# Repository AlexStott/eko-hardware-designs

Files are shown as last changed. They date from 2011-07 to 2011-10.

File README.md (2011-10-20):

Energy Kiosk Observer Hardware Schematics
=========================================

This project includes hardware schematics for the Energy Kiosk Observer datalogging system for e.quinox (www.e.quinox.org).

Cadsoft EAGLE is the tool of choice when designing PCBs, although some designs are being moved to RS DesignSpark.

Contents
--------

The following designs are included in this repository

* [AC Sensors](http://e.quinox.org/wiki/Datalogger:AC_Sensors): Isolated Power Sensing for 230VAC lines rated at 15A~.
* [Atmospheric](http://e.quinox.org/wiki/Datalogger:Atmospheric_Sensors): Light, Temperature and Humidity Sensing Package.
* [DC Sensor Solar](http://e.quinox.org/wiki/Datalogger:DC_Sensors): A 3x current, 1x voltage sensor package for power measurements on parallel connected solar panels.
* [DC Sensor](http://e.quinox.org/wiki/Datalogger:DC_Sensors): A 1x current, 1x voltage DC power sensor prototype rated at 30A~.
* [EKO Base](http://e.quinox.org/wiki/Datalogger:Mainboard): The Datalogger Mainboard with Network connectors and GPRS/3G modem.
* [Panelised]: Panelised designs for distribution to fabricator.
* [RS232_Barcode_Interface](http://e.quinox.org/wiki/Datalogger:Barcode_Scanner): An interface to a RS232 barcode scanner. Built for use with the SureElectronics PIC24F starter kit.
* [StorageBat_PSU](http://e.quinox.org/wiki/Datalogger:Battery_Sensors): A 1x voltage sensor for measurement of battery voltages.
* [Test_RS485](http://e.quinox.org/wiki/Datalogger:Test_Tools): A FTDI UM232 to RS485 adaptor utilising a SP483E line driver.
* [ekobbr2](http://e.quinox.org/wiki/Datalogger:Baseboard): PIC24F based sensor baseboard design.

Notes
-----

Currently the BoMs for these designs are not included in the repository. Order summaries are available on docs.ekohub.org or through the technical team wiki.

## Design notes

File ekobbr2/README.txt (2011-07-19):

Energy Kiosk Observer - Revision 1 AC sensor board 230V/5A
==========================================================

Design: Charith Amarasinghe

Designs
-------
Baseboard.brd/baseboard.sch - Revision 3 of the generic EKO sensor board

Features
********
PIC24F16KA102 in SOIC packaging
Integrated 32.768kHz crystal oscillator
3x Diagnostic LEDs (Power,TX,RX)
RX/TX can be disconnected from SP483E driver
Transient Voltage Suppressors on All Bus Lines
Interrupt Line

Changes from R2
***************
Included chip 7407D, 6x buffer instead of single buffer
Included Interrupt line connected to Pic AN2
Removed 2x debug LEDs
Removed end of sensor cable jumpers + resistors

Changes from R1
***************
All SMT components
PCB Stacking vs. Wire Connectors

Libraries
---------

eko-parts.lbr   - main eko-parts eagle library

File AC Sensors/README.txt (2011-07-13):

Energy Kiosk Observer - Revision 1 AC sensor board 230V/5A
==========================================================

Design: Azrul Mohamad

Designs
--------

ACBoard1.brd/ACBoard1.sch - Initial design, obsolete
ACBoard2.brd/ACBoard2.sch - Current, docks with Revision 2 SBB

Libraries
---------

Pauls_parts.lbr - Symbol for ACS712, Myrra Xfmr. Rename.
eko-parts.lbr   - Older version of main eko-parts eagle library (Consolidate)
Sensor.lbr	- Obsolete

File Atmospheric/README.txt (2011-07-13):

Energy Kiosk Observer - Revision 1 Atmospheric Sensor Humidity/Light/Temperature
=================================================================================

Design: Azrul Mohamad
Layout: Charith Amarasinghe

Boards
------

Atmospheric.brd/Atmospheric.sch - Atmospheric sensor for Revision 2 SBB
Supports accurate temperature measurement with a MCP9800
Light measured to human-eye response (Lux) by TAOS TSL2561
Relative Humidity measurement with Honeywell humidity sensor (capacitive, use PIC CTMU to measure)

Changes
------

07/06/2011	 Initial revision sent for manufacture
13/06/2011	 Increased mounting hole size to M3
		 
Libraries
--------

Atmospheric.lbr - TSL2561, MCP9800 and Generic Cap

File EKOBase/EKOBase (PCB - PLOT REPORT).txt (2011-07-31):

PLOT REPORT
-----------

Report File    : C:\Users\ca508\Dropbox\eagle\eko-hardware-designs\EKOBase\EKOBase (PCB - PLOT REPORT).txt
Report Written : Monday, August 01, 2011
Project Path   : C:\Users\ca508\Dropbox\eagle\eko-hardware-designs\EKOBase\EKOBase.prj
Design Path    : C:\Users\ca508\Dropbox\eagle\eko-hardware-designs\EKOBase\EKOBase.pcb
Design Title   : 
Created        : 28/05/2011 14:42:59
Last Saved     : 31/07/2011 23:47:38
Editing Time   : 3080 min
Units          : mm (precision 4)

DEVICE SETTINGS
---------------

---------------
Gerber Settings
---------------

    Leading zero suppression.
    G01 assumed throughout.
    Line termination <*> <CR> <LF>.
    2.3 format absolute inches.

    Format commands defined in Gerber file.
    Aperture table defined in Gerber file.
    Hardware arcs allowed.

--------------
Drill Settings
--------------

    Excellon Format 1
    Format 2.3 absolute in mm.
    No zero suppression.

PLOTS OUTPUT
------------
    Plot Job: "C:\Users\ca508\Dropbox\eagle\eko-hardware-designs\EKOBase\EKOBase.mop"

Gerber Output
-------------

    "C:\Users\ca508\Dropbox\eagle\eko-hardware-designs\EKOBase\Gerber\EKOBase - Top Silkscreen.gbr"

    Layers:
    -------
    Top Silkscreen

    D-Code    Shape  (thou)
    -----------------------
    D22       Round 1
    D96       Round 10
    D97       Round 16
    D98       Round 8
    D111       Round 6
    D113       Round 4
    D115       Round 5
    D124       Round 3
    D146       Round 16
    D147       Round 12
    D148       Round 8
    D149       Round 3
    D150       Round 4
    D151       Round 20
    D152       Round 12
    D153       Round 3
    D154       Round 0

Gerber Output
-------------

    "C:\Users\ca508\Dropbox\eagle\eko-hardware-designs\EKOBase\Gerber\EKOBase - Top Copper.gbr"

    Layers:
    -------
    Top Copper

    D-Code    Shape  (thou)
    -----------------------
    D22       Round 1
    D95       Round 32
    D96       Round 10
    D99       Round 55
    D102       Square 60
    D103       Octagon 60
    D104       Square 70
    D105       Octagon 70
    D148       Round 8
    D150       Round 0
    D151       Square 236
    D152       Round 60
    D153       Rectangle 22 X 78 Rotation 90
    D154       Rectangle 16 X 36
    D155       Rectangle 39 X 43
    D156       Rectangle 27 X 39 Rotation 90
    D157       Rectangle 161 X 163 Rotation 90
    D158       Rectangle 51 X 60
    D159       Rectangle 39 X 43 Rotation 90
    D160       Rectangle 51 X 60 Rotation 90
    D161       Oval 60 X 110 Rotation 90
    D162       Rectangle 24 X 87
    D163       Oval 60 X 110
    D164       Rectangle 63 X 71 Rotation 90
    D165       Rectangle 63 X 71
    D166       Rectangle 70 X 93
    D167       Round 160
    D168       Rectangle 161 X 163
    D169       Rectangle 43 X 82 Rotation 90
    D170       Rectangle 105 X 132
    D171       Rectangle 80 X 95
    D172       Square 95
    D173       Rectangle 24 X 60
    D174       Round 86
    D175       Rectangle 18 X 39 Rotation 90
    D176       Rectangle 80 X 95 Rotation 90
    D177       Round 60
    D178       Rectangle 17 X 69 Rotation 90
    D179       Rectangle 47 X 169 Rotation 90
    D180       Rectangle 47 X 79 Rotation 90
    D181       Rectangle 83 X 94 Rotation 90
    D182       Rectangle 102 X 114 Rotation 90
    D183       Rectangle 51 X 75 Rotation 90
    D184       Rectangle 55 X 77 Rotation 90
    D185       Rectangle 83 X 87 Rotation 90
    D186       Round 70
    D187       Round 60
    D188       Round 56
    D189       Round 48
    D190       Round 30
    D191       Round 24
    D192       Round 15
    D193       Round 50

Gerber Output
-------------

    "C:\Users\ca508\Dropbox\eagle\eko-hardware-designs\EKOBase\Gerber\EKOBase - Top Copper (Paste).gbr"

    Layers:
    -------
    Top Copper

    D-Code    Shape  (thou)
    -----------------------
    D10       Rectangle 18 X 74 Rotation 90
    D11       Rectangle 12 X 32
    D12       Rectangle 35 X 39
    D13       Rectangle 23 X 35 Rotation 90
    D14       Rectangle 157 X 159 Rotation 90
    D15       Rectangle 47 X 56
    D16       Rectangle 35 X 39 Rotation 90
    D17       Rectangle 47 X 56 Rotation 90
    D18       Rectangle 20 X 83
    D19       Rectangle 59 X 67 Rotation 90
    D70       Rectangle 59 X 67
    D71       Rectangle 66 X 89
    D20       Rectangle 157 X 159
    D21       Rectangle 39 X 78 Rotation 90
    D22       Rectangle 101 X 128
    D23       Rectangle 76 X 91
    D24       Square 91
    D25       Rectangle 20 X 56
    D26       Rectangle 14 X 35 Rotation 90
    D27       Rectangle 76 X 91 Rotation 90
    D28       Rectangle 13 X 65 Rotation 90
    D29       Rectangle 43 X 165 Rotation 90
    D72       Rectangle 43 X 75 Rotation 90
    D73       Rectangle 79 X 90 Rotation 90
    D74       Rectangle 98 X 110 Rotation 90
    D75       Rectangle 47 X 71 Rotation 90
    D76       Rectangle 51 X 73 Rotation 90
    D77       Rectangle 79 X 83 Rotation 90

Gerber Output
-------------

    "C:\Users\ca508\Dropbox\eagle\eko-hardware-designs\EKOBase\Gerber\EKOBase - Top Solder Mask.gbr"

    Layers:
    -------
    Top Solder Mask

    D-Code    Shape  (thou)
    -----------------------
    D78       Square 242
    D79       Round 8
    D80       Round 66
    D81       Square 76
    D82       Octagon 70
    D83       Square 66
    D84       Octagon 60
    D85       Rectangle 28 X 84 Rotation 90
    D86       Rectangle 22 X 42
    D87       Rectangle 45 X 49
    D88       Rectangle 33 X 45 Rotation 90
    D89       Rectangle 167 X 169 Rotation 90
    D90       Rectangle 57 X 66
    D91       Rectangle 45 X 49 Rotation 90
    D92       Rectangle 57 X 66 Rotation 90
    D93       Oval 66 X 116 Rotation 90
    D94       Rectangle 30 X 93
    D95       Oval 66 X 116
    D96       Rectangle 69 X 77 Rotation 90
    D97       Rectangle 69 X 77
    D98       Rectangle 76 X 99
    D99       Round 61
    D100       Round 166
    D101       Rectangle 167 X 169
    D102       Rectangle 49 X 88 Rotation 90
    D103       Rectangle 111 X 138
    D104       Rectangle 86 X 101
    D105       Square 101
    D106       Rectangle 30 X 66
    D107       Round 92
    D108       Rectangle 24 X 45 Rotation 90
    D109       Rectangle 86 X 101 Rotation 90
    D110       Round 66
    D111       Rectangle 23 X 75 Rotation 90
    D112       Rectangle 53 X 175 Rotation 90
    D113       Rectangle 53 X 85 Rotation 90
    D114       Rectangle 89 X 100 Rotation 90
    D115       Rectangle 108 X 120 Rotation 90
    D116       Rectangle 57 X 81 Rotation 90
    D117       Rectangle 61 X 83 Rotation 90
    D118       Rectangle 89 X 93 Rotation 90
    D119       Round 76
    D120       Round 1
    D121       Round 66
    D122       Round 62
    D123       Round 54
    D124       Round 38

Gerber Output
-------------

    "C:\Users\ca508\Dropbox\eagle\eko-hardware-designs\EKOBase\Gerber\EKOBase - Bottom Copper.gbr"

    Layers:
    -------
    Bottom Copper

    D-Code    Shape  (thou)
    -----------------------
    D79       Round 8
    D106       Round 10
    D107       Square 70
    D108       Octagon 70
    D109       Square 60
    D110       Octagon 60
    D111       Rectangle 70 X 93 Rotation 90
    D112       Round 55
    D113       Round 32
    D114       Round 20
    D150       Round 0
    D151       Square 236
    D152       Round 60
    D155       Rectangle 39 X 43
    D158       Rectangle 51 X 60
    D159       Rectangle 39 X 43 Rotation 90
    D160       Rectangle 51 X 60 Rotation 90
    D161       Oval 60 X 110 Rotation 90
    D163       Oval 60 X 110
    D165       Rectangle 63 X 71
    D167       Round 160
    D174       Round 86
    D177       Round 60
    D186       Round 70
    D187       Round 60
    D188       Round 56
    D189       Round 48
    D190       Round 30
    D191       Round 24
    D192       Round 15
    D193       Round 50

Gerber Output
-------------

    "C:\Users\ca508\Dropbox\eagle\eko-hardware-designs\EKOBase\Gerber\EKOBase - Bottom Copper (Paste).gbr"

    Layers:
    -------
    Bottom Copper

    D-Code    Shape  (thou)
    -----------------------
    D10       Rectangle 66 X 89 Rotation 90
    D11       Rectangle 59 X 67
    D12       Rectangle 47 X 56
    D13       Rectangle 47 X 56 Rotation 90
    D14       Rectangle 35 X 39
    D15       Rectangle 35 X 39 Rotation 90

Gerber Output
-------------

    "C:\Users\ca508\Dropbox\eagle\eko-hardware-designs\EKOBase\Gerber\EKOBase - Bottom Silkscreen.gbr"

    Layers:
    -------
    Bottom Silkscreen

    D-Code    Shape  (thou)
    -----------------------
    D16       Round 25
    D17       Round 8
    D18       Round 5
    D19       Round 8

Gerber Output
-------------

    "C:\Users\ca508\Dropbox\eagle\eko-hardware-designs\EKOBase\Gerber\EKOBase - Bottom Solder Mask.gbr"

    Layers:
    -------
    Bottom Solder Mask

    D-Code    Shape  (thou)
    -----------------------
    D17       Round 8
    D70       Square 242
    D71       Round 66
    D20       Square 76
    D21       Octagon 70
    D22       Square 66
    D23       Octagon 60
    D24       Rectangle 76 X 99 Rotation 90
    D25       Oval 66 X 116 Rotation 90
    D26       Oval 66 X 116
    D27       Round 61
    D28       Round 166
    D29       Round 92
    D72       Rectangle 69 X 77
    D73       Round 66
    D74       Round 76
    D75       Rectangle 57 X 66
    D76       Rectangle 57 X 66 Rotation 90
    D77       Round 66
    D78       Rectangle 45 X 49
    D79       Rectangle 45 X 49 Rotation 90
    D80       Round 62
    D81       Round 54
    D82       Round 38

NC Drill Output
---------------

    Output:
    -------
    Plated Round Drill Holes
    Plated Slots
    Plated Board Outlines

    "C:\Users\ca508\Dropbox\eagle\eko-hardware-designs\EKOBase\Gerber\EKOBase - Drill Data - Through Hole.drl"

    Tool             Size        Count  ID
    --------------------------------------
    T001        00.016 in           49   L
    T002        00.024 in           15   B
    T003        00.030 in           28   C
    T004        00.032 in           94   E
    T005        00.035 in            2   K
    T006        00.035 in           24   F
    T007        00.040 in           10   D
    T008        00.055 in            2   J
    T009        00.062 in            4   H
    T010        00.128 in            6   G
    T011        00.154 in            8   A
    --------------------------------------
    All                            242
    --------------------------------------

NC Drill Output
---------------

    Output:
    -------
    Unplated Round Drill Holes
    Unplated Slots
    Unplated Board Outlines

    "C:\Users\ca508\Dropbox\eagle\eko-hardware-designs\EKOBase\Gerber\EKOBase - Drill Data - Through Hole (Unplated).drl"

    Tool             Size        Count  ID
    --------------------------------------
    T001        00.025 in            1   
    --------------------------------------
    All                              1
    --------------------------------------

Gerber Output
-------------

    "C:\Users\ca508\Dropbox\eagle\eko-hardware-designs\EKOBase\Gerber\EKOBase - Drill Ident Drawing - Through Hole.gbr"

    Layers:
    -------

    Drill Ident Drawing
    -------------------

    Drill     Plated    Size      Shape     ID        
    --------------------------------------------------
    154       Y         100       Round     A         
    24        Y         100       Round     B         
    30        Y         100       Round     C         
    40        Y         100       Round     D         
    32        Y         100       Round     E         
    35        Y         100       Round     F         
    128       Y         100       Round     G         
    62        Y         100       Round     H         
    55        Y         100       Round     J         
    35        Y         100       Round     K         
    16        Y         100       Round     L         
    --------------------------------------------------

    D-Code    Shape  (thou)
    -----------------------
    D18       Round 5
    D83       Round 100

Gerber Output
-------------

    "C:\Users\ca508\Dropbox\eagle\eko-hardware-designs\EKOBase\Gerber\EKOBase - Board Outline.gbr"

    Layers:
    -------
    Board Outlines

    D-Code    Shape  (thou)
    -----------------------
    D18       Round 5

End Of Report.

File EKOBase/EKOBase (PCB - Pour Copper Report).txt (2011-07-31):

Pour Copper Report
------------------

Report File    : C:\Users\ca508\Dropbox\eagle\eko-hardware-designs\EKOBase\EKOBase (PCB - Pour Copper Report).txt
Report Written : Monday, August 01, 2011
Project Path   : C:\Users\ca508\Dropbox\eagle\eko-hardware-designs\EKOBase\EKOBase.prj
Design Path    : C:\Users\ca508\Dropbox\eagle\eko-hardware-designs\EKOBase\EKOBase.pcb
Design Title   : 
Created        : 28/05/2011 14:42:59
Last Saved     : 31/07/2011 23:43:01
Editing Time   : 3076 min
Units          : mm (precision 4)

End Of Report.

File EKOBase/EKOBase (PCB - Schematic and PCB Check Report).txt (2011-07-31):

Schematic and PCB Check Report
------------------------------

Report File    : C:\Users\ca508\Dropbox\eagle\eko-hardware-designs\EKOBase\EKOBase (PCB - Schematic and PCB Check Report).txt
Report Written : Monday, August 01, 2011
Project Path   : C:\Users\ca508\Dropbox\eagle\eko-hardware-designs\EKOBase\EKOBase.prj
Design Path    : C:\Users\ca508\Dropbox\eagle\eko-hardware-designs\EKOBase\EKOBase.pcb
Design Title   : 
Created        : 28/05/2011 14:42:59
Last Saved     : 31/07/2011 23:12:49
Editing Time   : 3044 min
Units          : mm (precision 4)

Checking integrity of Schematic "C:\Users\ca508\Dropbox\eagle\eko-hardware-designs\EKOBase\EKOBase.prj" with PCB "C:\Users\ca508\Dropbox\eagle\eko-hardware-designs\EKOBase\EKOBase.pcb".

End Of Report.

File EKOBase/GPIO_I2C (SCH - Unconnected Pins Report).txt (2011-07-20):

Unconnected Pins Report
-----------------------

Report File    : C:\Users\ca508\Dropbox\DesignSpark Projects\EKOBase\GPIO_I2C (SCH - Unconnected Pins Report).txt
Report Written : Saturday, May 28, 2011
Project Path   : C:\Users\ca508\Dropbox\DesignSpark Projects\EKOBase\EKOBase.prj
Design Path    : C:\Users\ca508\Dropbox\DesignSpark Projects\EKOBase\GPIO_I2C.sch
Design Title   : 
Created        : 
Last Saved     : 28/05/2011 00:56:19
Editing Time   : 801 min
Units          : thou (precision 2)

Component U1  Pin 6  A4
Component R4  Pin 3  
Component R4  Pin 4  
Component J1  Pin 1  
Component J1  Pin 25  
Component REF60  Pin 7  NC
Component REF60  Pin 8  INT
Component REF60  Pin 15  GP5
Component U6  Pin 1  NC
Component U6  Pin 4  NC
Component U7  Pin 1  NC
Component U7  Pin 4  NC
Component U9  Pin 1  NC
Component U9  Pin 4  NC
Component CONN1  Pin P$1  1
Component CONN1  Pin P$2  2
Component CONN1  Pin P$3  3
Component CONN1  Pin P$6  6
Component CONN2  Pin P$1  1
Component CONN2  Pin P$2  2
Component CONN2  Pin P$3  3
Component CONN2  Pin P$6  6
Component U11  Pin 1  NC
Component U11  Pin 4  NC
Component U12  Pin 1  NC
Component U12  Pin 4  NC

Unconnected pins found : 26

End Of Report.

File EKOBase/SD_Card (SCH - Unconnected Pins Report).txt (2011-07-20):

Unconnected Pins Report
-----------------------

Report File    : C:\Users\ca508\Dropbox\DesignSpark Projects\EKOBase\SD_Card (SCH - Unconnected Pins Report).txt
Report Written : Saturday, May 28, 2011
Project Path   : C:\Users\ca508\Dropbox\DesignSpark Projects\EKOBase\EKOBase.prj
Design Path    : C:\Users\ca508\Dropbox\DesignSpark Projects\EKOBase\SD_Card.sch
Design Title   : 
Created        : 
Last Saved     : 28/05/2011 03:20:28
Editing Time   : 1602 min
Units          : mil (precision 0)

Component U1  Pin 6  A4
Component J1  Pin 1  
Component J1  Pin 25  
Component REF60  Pin 7  NC
Component REF60  Pin 8  INT
Component REF60  Pin 15  GP5
Component U6  Pin 1  NC
Component U6  Pin 4  NC
Component U7  Pin 1  NC
Component U7  Pin 4  NC
Component U9  Pin 1  NC
Component U9  Pin 4  NC
Component CONN1  Pin P$1  1
Component CONN1  Pin P$2  2
Component CONN1  Pin P$3  3
Component CONN1  Pin P$6  6
Component CONN2  Pin P$1  1
Component CONN2  Pin P$2  2
Component CONN2  Pin P$3  3
Component CONN2  Pin P$6  6
Component U11  Pin 1  NC
Component U11  Pin 4  NC
Component U12  Pin 1  NC
Component U12  Pin 4  NC

Unconnected pins found : 24

End Of Report.

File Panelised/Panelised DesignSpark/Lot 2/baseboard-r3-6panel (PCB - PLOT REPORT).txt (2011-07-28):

PLOT REPORT
-----------

Report File    : C:\Users\ca508\Dropbox\eagle\eko-hardware-designs\Panelised\Panelised DesignSpark\Lot 2\baseboard-r3-6panel (PCB - PLOT REPORT).txt
Report Written : Thursday, July 28, 2011
Project Path   : C:\Users\ca508\Dropbox\eagle\eko-hardware-designs\Panelised\Panelised DesignSpark\Lot 2\Lot 2.prj
Design Path    : C:\Users\ca508\Dropbox\eagle\eko-hardware-designs\Panelised\Panelised DesignSpark\Lot 2\baseboard-r3-6panel.pcb
Design Title   : 
Created        : 27/07/2011 22:50:58
Last Saved     : 28/07/2011 00:26:40
Editing Time   : 105 min
Units          : thou (precision 0)

DEVICE SETTINGS
---------------

---------------
Gerber Settings
---------------

    Leading zero suppression.
    G01 assumed throughout.
    Line termination <*> <CR> <LF>.
    2.3 format absolute inches.

    Format commands defined in Gerber file.
    Aperture table defined in Gerber file.
    Hardware arcs allowed.

--------------
Drill Settings
--------------

    Excellon Format 1
    Format 2.3 absolute in mm.
    No zero suppression.

PLOTS OUTPUT
------------
    Plot Job: "C:\Users\ca508\Dropbox\eagle\eko-hardware-designs\Panelised\Panelised DesignSpark\Lot 2\baseboard-r3-6panel.mop"

Gerber Output
-------------

    "C:\Users\ca508\Dropbox\eagle\eko-hardware-designs\Panelised\Panelised DesignSpark\Lot 2\Gerber\baseboard-r3-6panel - Top Silk.gbr"

    Layers:
    -------
    Top Silk

    D-Code    Shape  (thou)
    -----------------------
    D22       Round 1
    D96       Round 10
    D97       Round 16
    D98       Round 8
    D109       Round 8
    D110       Round 5
    D111       Round 6
    D112       Round 4
    D113       Round 4
    D115       Round 5
    D116       Round 8
    D117       Round 17
    D118       Round 19
    D119       Round 9
    D120       Round 13
    D121       Round 11
    D122       Round 6
    D123       Round 2
    D124       Round 3
    D125       Round 7
    D126       Round 0
    D127       Round 7

Gerber Output
-------------

    "C:\Users\ca508\Dropbox\eagle\eko-hardware-designs\Panelised\Panelised DesignSpark\Lot 2\Gerber\baseboard-r3-6panel - Top.gbr"

    Layers:
    -------
    Top

    D-Code    Shape  (thou)
    -----------------------
    D95       Round 32
    D96       Round 10
    D97       Round 16
    D98       Round 8
    D99       Round 55
    D100       Round 136
    D102       Square 60
    D103       Octagon 60
    D104       Square 70
    D105       Octagon 70
    D106       Rectangle 51 X 59 Rotation 90
    D107       Octagon 40
    D108       Square 166
    D115       Round 5
    D128       Rectangle 43 X 39 Rotation 90
    D129       Rectangle 43 X 39
    D130       Rectangle 77 X 98
    D131       Rectangle 63 X 71 Rotation 90
    D132       Rectangle 100 X 98 Rotation 90
    D133       Rectangle 64 X 86 Rotation 90
    D134       Rectangle 24 X 87 Rotation 90
    D135       Rectangle 26 X 80 Rotation 90
    D136       Rectangle 24 X 59 Rotation 90
    D137       Rectangle 48 X 88 Rotation 90
    D138       Rectangle 142 X 87 Rotation 90
    D139       Square 157
    D140       Rectangle 46 X 63
    D141       Round 51
    D142       Round 59
    D143       Rectangle 24 X 43 Rotation 90
    D144       Rectangle 26 X 67

Gerber Output
-------------

    "C:\Users\ca508\Dropbox\eagle\eko-hardware-designs\Panelised\Panelised DesignSpark\Lot 2\Gerber\baseboard-r3-6panel - Top Mask.gbr"

    Layers:
    -------
    Top Mask

    D-Code    Shape  (thou)
    -----------------------
    D10       Rectangle 49 X 45 Rotation 90
    D11       Rectangle 49 X 45
    D12       Rectangle 83 X 104
    D13       Rectangle 69 X 77 Rotation 90
    D14       Rectangle 106 X 104 Rotation 90
    D15       Round 61
    D16       Round 142
    D17       Rectangle 70 X 92 Rotation 90
    D18       Rectangle 30 X 93 Rotation 90
    D19       Rectangle 32 X 86 Rotation 90
    D70       Rectangle 30 X 65 Rotation 90
    D71       Rectangle 54 X 94 Rotation 90
    D20       Rectangle 148 X 93 Rotation 90
    D21       Square 163
    D22       Round 1
    D23       Square 66
    D24       Octagon 60
    D25       Square 76
    D26       Octagon 70
    D27       Rectangle 57 X 65 Rotation 90
    D28       Rectangle 52 X 69
    D29       Round 57
    D72       Round 65
    D73       Rectangle 30 X 49 Rotation 90
    D74       Rectangle 32 X 73
    D75       Octagon 40
    D76       Square 172
    D115       Round 5

Gerber Output
-------------

    "C:\Users\ca508\Dropbox\eagle\eko-hardware-designs\Panelised\Panelised DesignSpark\Lot 2\Gerber\baseboard-r3-6panel - Bottom.gbr"

    Layers:
    -------
    Bottom

    D-Code    Shape  (thou)
    -----------------------
    D95       Round 32
    D96       Round 10
    D97       Round 16
    D98       Round 8
    D99       Round 55
    D100       Round 136
    D101       Rectangle 64 X 86
    D102       Square 60
    D103       Octagon 60
    D104       Square 70
    D105       Octagon 70
    D106       Rectangle 51 X 59 Rotation 90
    D107       Octagon 40
    D108       Square 166

Gerber Output
-------------

    "C:\Users\ca508\Dropbox\eagle\eko-hardware-designs\Panelised\Panelised DesignSpark\Lot 2\Gerber\baseboard-r3-6panel - Bot Silk.gbr"

    Layers:
    -------
    Bot Silk

    D-Code    Shape  (thou)
    -----------------------
    D109       Round 8
    D110       Round 5
    D111       Round 6
    D112       Round 4
    D113       Round 4

Gerber Output
-------------

    "C:\Users\ca508\Dropbox\eagle\eko-hardware-designs\Panelised\Panelised DesignSpark\Lot 2\Gerber\baseboard-r3-6panel - Bot Mask.gbr"

    Layers:
    -------
    Bot Mask

    D-Code    Shape  (thou)
    -----------------------
    D15       Round 61
    D16       Round 142
    D23       Square 66
    D24       Octagon 60
    D25       Square 76
    D26       Octagon 70
    D27       Rectangle 57 X 65 Rotation 90
    D75       Octagon 40
    D76       Square 172
    D115       Round 5
    D145       Rectangle 70 X 92

NC Drill Output
---------------

    Output:
    -------
    Plated Round Drill Holes
    Plated Slots
    Plated Board Outlines

    "C:\Users\ca508\Dropbox\eagle\eko-hardware-designs\Panelised\Panelised DesignSpark\Lot 2\Gerber\baseboard-r3-6panel - Drill Data - Through Hole.drl"

    Tool             Size        Count  ID
    --------------------------------------
    T001        00.024 in          246   B
    T002        00.035 in           96   F
    T003        00.040 in          180   D
    T004        00.126 in           24   I
    T005        00.128 in           24   G
    --------------------------------------
    All                            570
    --------------------------------------

NC Drill Output
---------------

    Output:
    -------
    Unplated Round Drill Holes
    Unplated Slots
    Unplated Board Outlines

    "C:\Users\ca508\Dropbox\eagle\eko-hardware-designs\Panelised\Panelised DesignSpark\Lot 2\Gerber\baseboard-r3-6panel - Drill Data - Through Hole (Unplated).drl"

    Tool             Size        Count  ID
    --------------------------------------
    T001        00.025 in            1   
    --------------------------------------
    All                              1
    --------------------------------------

Gerber Output
-------------

    "C:\Users\ca508\Dropbox\eagle\eko-hardware-designs\Panelised\Panelised DesignSpark\Lot 2\Gerber\baseboard-r3-6panel - Drill Ident Drawing - Through Hole.gbr"

    Layers:
    -------

    Drill Ident Drawing
    -------------------

    Drill     Plated    Size      Shape     ID        
    --------------------------------------------------
    24        Y         100       Round     B         
    40        Y         100       Round     D         
    35        Y         100       Round     F         
    128       Y         100       Round     G         
    126       Y         100       Round     I         
    --------------------------------------------------

    D-Code    Shape  (thou)
    -----------------------
    D114       Round 100
    D115       Round 5

Gerber Output
-------------

    "C:\Users\ca508\Dropbox\eagle\eko-hardware-designs\Panelised\Panelised DesignSpark\Lot 2\Gerber\baseboard-r3-6panel - Dimension.gbr"

    Layers:
    -------
    Board Outlines

    D-Code    Shape  (thou)
    -----------------------
    D22       Round 1

End Of Report.

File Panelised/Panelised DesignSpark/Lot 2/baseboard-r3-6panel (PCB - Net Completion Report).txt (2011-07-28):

Net Completion Report
---------------------

Report File    : C:\Users\ca508\Dropbox\eagle\eko-hardware-designs\Panelised\Panelised DesignSpark\Lot 2\baseboard-r3-6panel (PCB - Net Completion Report).txt
Report Written : Thursday, July 28, 2011
Project Path   : C:\Users\ca508\Dropbox\eagle\eko-hardware-designs\Panelised\Panelised DesignSpark\Lot 2\Lot 2.prj
Design Path    : C:\Users\ca508\Dropbox\eagle\eko-hardware-designs\Panelised\Panelised DesignSpark\Lot 2\baseboard-r3-6panel.pcb
Design Title   : 
Created        : 27/07/2011 22:50:58
Last Saved     : 27/07/2011 23:07:23
Editing Time   : 21 min
Units          : thou (precision 0)

No breaks found, all nets are fully routed.
End Of Report.

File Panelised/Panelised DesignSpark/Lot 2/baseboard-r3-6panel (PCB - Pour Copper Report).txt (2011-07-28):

Pour Copper Report
------------------

Report File    : C:\Users\ca508\Dropbox\eagle\eko-hardware-designs\Panelised\Panelised DesignSpark\Lot 2\baseboard-r3-6panel (PCB - Pour Copper Report).txt
Report Written : Wednesday, July 27, 2011
Design Path    : C:\Users\ca508\Dropbox\eagle\eko-hardware-designs\Panelised\Panelised DesignSpark\Lot 2\baseboard-r3-6panel.pcb
Design Title   : 
Created        : 27/07/2011 22:50:58
Last Saved     : 
Editing Time   : 6 min
Units          : thou (precision 0)

C47.2 at 8842,5975 has no thermal spokes
C52.2 at 8908,5900 has no thermal spokes
C53.2 at 9175,5308 has no thermal spokes
IC21.7 at 10023,5925 has no thermal spokes
U6.27 at 8875,5813 has no thermal spokes
Via at 8838,6038 has no thermal spokes

End Of Report.

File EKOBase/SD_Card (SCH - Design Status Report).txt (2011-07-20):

Design Status Report
--------------------

Report File    : C:\Users\ca508\Dropbox\DesignSpark Projects\EKOBase\SD_Card (SCH - Design Status Report).txt
Report Written : Saturday, May 28, 2011
Project Path   : C:\Users\ca508\Dropbox\DesignSpark Projects\EKOBase\EKOBase.prj
Design Path    : C:\Users\ca508\Dropbox\DesignSpark Projects\EKOBase\SD_Card.sch
Design Title   : 
Created        : 
Last Saved     : 28/05/2011 14:42:00
Editing Time   : 1607 min
Units          : mil (precision 0)

Component List
--------------
Comp Type     Package      Components   Pins   Unused Gates

SN74AVC4T774    SOIC            2       32       0      
A4              MISC            6       0        6      
0V                              34      34       0      
FROM                            62      62       0      
SDBMF           SDBMF-009XXBXX2 1       12       0      
+1V8                            12      12       0      
+3V3                            16      16       0      
2mmElectrolyticCap DSC             1       2        0      
TO                              26      26       0      
R 0.1W SMTF 10K SM0805          31      62       0      
06035C102KATDA  SM0603          6       12       0      
R 0.063W SMTF 33 SM0603          12      24       0      
28PIN2ROW2.54mmCON CONN            1       28       0      
F-1X02-SIP-100-40 SIP-100-02-40   1       2        0      
+5V_ISO                         11      11       0      
0V_ISO                          16      16       0      
F-2X02-DIL-100  DIL-100-2X02    1       4        0      
+5V                             10      10       0      
SM6T            SOD             5       10       0      
MCP23008-X_SO   SOIC18-W_MC     1       18       0      
PCA9306         DCT             1       8        0      
R 0.063W SMTF 180K SM0603          2       4        0      
F-1X04-SIP-100-40 SIP-100-04-40   1       4        0      
74LVC1G07DBV    SOT23-5         4       16       0      
LED_SMT         PLCC2           9       18       0      
R 0.1W SMTF 560 SM0805          5       10       0      
R 0.063W SMTF 10K SM0603          4       8        0      
0603YC104KATDA  SM0603          9       18       0      
TXS0102         DCU             2       16       0      
6N137           DIP             5       40       0      
MAX483ESA       SO-G8_1         1       8        0      
1206YG225ZATEA  SM1206          8       16       0      
LED_SMT_0603    0603            2       4        0      
MHRJJ88NFRA     MHRJJ8NFRA      2       16       0      
BD6517F         SOP             1       8        0      
LM1117          SOT-223         2       6        0      
TANTALUM_B      CASE_B          2       4        0      
TANTALUM_C      CASE_C          2       4        0      

Total:                          317     601      6      

Total number of unused gates in the component bin 6.

Net List
--------
Net Class     Nets

Signal          91     
Ground          1      
Power           7      

Total:          99     

End Of Report.

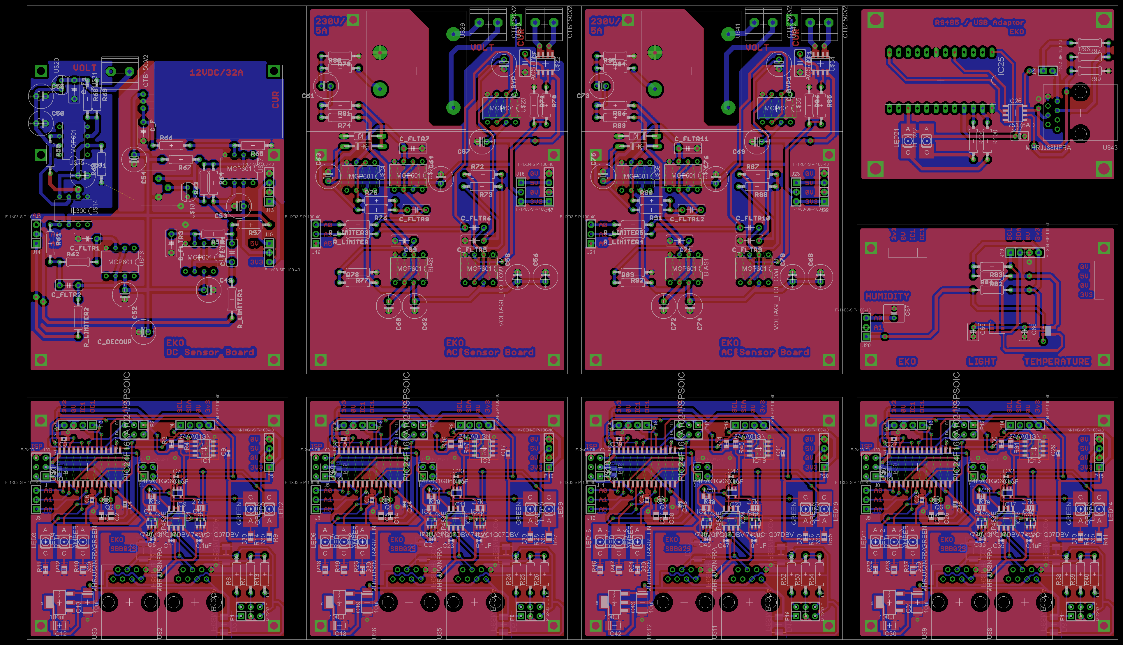
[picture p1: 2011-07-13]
equinox.datalogger.boards.png

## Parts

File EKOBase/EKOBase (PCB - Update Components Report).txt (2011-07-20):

Update Components Report
------------------------

Report File    : C:\Users\ca508\Dropbox\DesignSpark Projects\EKOBase\EKOBase (PCB - Update Components Report).txt
Report Written : Saturday, May 28, 2011
Project Path   : C:\Users\ca508\Dropbox\DesignSpark Projects\EKOBase\EKOBase.prj
Design Path    : C:\Users\ca508\Dropbox\DesignSpark Projects\EKOBase\EKOBase.pcb
Design Title   : 
Created        : 28/05/2011 01:05:15
Last Saved     : 28/05/2011 01:10:23
Editing Time   : 5 min
Units          : mm (precision 2)

Library Files:
	C:\Users\Public\Documents\DesignSpark PCB\Library\3m.cml
	C:\Users\Public\Documents\DesignSpark PCB\Library\74hc.cml
	C:\Users\Public\Documents\DesignSpark PCB\Library\74hct.cml
	C:\Users\Public\Documents\DesignSpark PCB\Library\74ls.cml
	C:\Users\Public\Documents\DesignSpark PCB\Library\74_little_us.cml
	C:\Users\Public\Documents\DesignSpark PCB\Library\4000.cml
	C:\Users\Public\Documents\DesignSpark PCB\Library\actel.cml
	C:\Users\Public\Documents\DesignSpark PCB\Library\ad.cml
	C:\Users\Public\Documents\DesignSpark PCB\Library\adsp.cml
	C:\Users\Public\Documents\DesignSpark PCB\Library\altera.cml
	C:\Users\Public\Documents\DesignSpark PCB\Library\alteracyclone.cml
	C:\Users\Public\Documents\DesignSpark PCB\Library\amp.cml
	C:\Users\Public\Documents\DesignSpark PCB\Library\atmel.cml
	C:\Users\Public\Documents\DesignSpark PCB\Library\atmel8051.cml
	C:\Users\Public\Documents\DesignSpark PCB\Library\atmelarm.cml
	C:\Users\Public\Documents\DesignSpark PCB\Library\atmelatsam7.cml
	C:\Users\Public\Documents\DesignSpark PCB\Library\atmelavr.cml
	C:\Users\Public\Documents\DesignSpark PCB\Library\avx.cml
	C:\Users\Public\Documents\DesignSpark PCB\Library\capacitor.cml
	C:\Users\Public\Documents\DesignSpark PCB\Library\coldfire.cml
	C:\Users\Public\Documents\DesignSpark PCB\Library\connector.cml
	C:\Users\Public\Documents\DesignSpark PCB\Library\con_header.cml
	C:\Users\Public\Documents\DesignSpark PCB\Library\csm.cml
	C:\Users\Public\Documents\DesignSpark PCB\Library\cypress.cml
	C:\Users\Public\Documents\DesignSpark PCB\Library\diode.cml
	C:\Users\Public\Documents\DesignSpark PCB\Library\discrete.cml
	C:\Users\Public\Documents\DesignSpark PCB\Library\dsm.cml
	C:\Users\Public\Documents\DesignSpark PCB\Library\eagle_res.cml
	C:\Users\Public\Documents\DesignSpark PCB\Library\eko_project.cml
	C:\Users\Public\Documents\DesignSpark PCB\Library\eko_project_eagle.cml
	C:\Users\Public\Documents\DesignSpark PCB\Library\fairchild.cml
	C:\Users\Public\Documents\DesignSpark PCB\Library\fairchild1.cml
	C:\Users\Public\Documents\DesignSpark PCB\Library\fairchildacex.cml
	C:\Users\Public\Documents\DesignSpark PCB\Library\farnell.cml
	C:\Users\Public\Documents\DesignSpark PCB\Library\fci.cml
	C:\Users\Public\Documents\DesignSpark PCB\Library\fuse.cml
	C:\Users\Public\Documents\DesignSpark PCB\Library\hamlin.cml
	C:\Users\Public\Documents\DesignSpark PCB\Library\hybrid.cml
	C:\Users\Public\Documents\DesignSpark PCB\Library\infineontc116x.cml
	C:\Users\Public\Documents\DesignSpark PCB\Library\intel8051.cml
	C:\Users\Public\Documents\DesignSpark PCB\Library\ir.cml
	C:\Users\Public\Documents\DesignSpark PCB\Library\lattice.cml
	C:\Users\Public\Documents\DesignSpark PCB\Library\lt.cml
	C:\Users\Public\Documents\DesignSpark PCB\Library\luminarycortex.cml
	C:\Users\Public\Documents\DesignSpark PCB\Library\maxim.cml
	C:\Users\Public\Documents\DesignSpark PCB\Library\maxim8051.cml
	C:\Users\Public\Documents\DesignSpark PCB\Library\maximmp.cml
	C:\Users\Public\Documents\DesignSpark PCB\Library\mc68hc.cml
	C:\Users\Public\Documents\DesignSpark PCB\Library\microchip.cml
	C:\Users\Public\Documents\DesignSpark PCB\Library\microchippic.cml
	C:\Users\Public\Documents\DesignSpark PCB\Library\molex.cml
	C:\Users\Public\Documents\DesignSpark PCB\Library\msp430.cml
	C:\Users\Public\Documents\DesignSpark PCB\Library\murata.cml
	C:\Users\Public\Documents\DesignSpark PCB\Library\natsemi.cml
	C:\Users\Public\Documents\DesignSpark PCB\Library\nxp-lpc32x0.cml
	C:\Users\Public\Documents\DesignSpark PCB\Library\omron.cml
	C:\Users\Public\Documents\DesignSpark PCB\Library\onsemi.cml
	C:\Users\Public\Documents\DesignSpark PCB\Library\opamps.cml
	C:\Users\Public\Documents\DesignSpark PCB\Library\pcb.cml
	C:\Users\Public\Documents\DesignSpark PCB\Library\philips80c51.cml
	C:\Users\Public\Documents\DesignSpark PCB\Library\philipsarm.cml
	C:\Users\Public\Documents\DesignSpark PCB\Library\philipsp89.cml
	C:\Users\Public\Documents\DesignSpark PCB\Library\philipsxa.cml
	C:\Users\Public\Documents\DesignSpark PCB\Library\picaxe.cml
	C:\Users\Public\Documents\DesignSpark PCB\Library\powerpc.cml
	C:\Users\Public\Documents\DesignSpark PCB\Library\qbsm.cml
	C:\Users\Public\Documents\DesignSpark PCB\Library\qcsm.cml
	C:\Users\Public\Documents\DesignSpark PCB\Library\qsm.cml
	C:\Users\Public\Documents\DesignSpark PCB\Library\quicklogic.cml
	C:\Users\Public\Documents\DesignSpark PCB\Library\relay.cml
	C:\Users\Public\Documents\DesignSpark PCB\Library\renesasr8c.cml
	C:\Users\Public\Documents\DesignSpark PCB\Library\resistor.cml
	C:\Users\Public\Documents\DesignSpark PCB\Library\rfmicro.cml
	C:\Users\Public\Documents\DesignSpark PCB\Library\schema.cml
	C:\Users\Public\Documents\DesignSpark PCB\Library\sm.cml
	C:\Users\Public\Documents\DesignSpark PCB\Library\sonycx.cml
	C:\Users\Public\Documents\DesignSpark PCB\Library\st-arm7.cml
	C:\Users\Public\Documents\DesignSpark PCB\Library\st.cml
	C:\Users\Public\Documents\DesignSpark PCB\Library\testpoint.cml
	C:\Users\Public\Documents\DesignSpark PCB\Library\ti.cml
	C:\Users\Public\Documents\DesignSpark PCB\Library\tms320.cml
	C:\Users\Public\Documents\DesignSpark PCB\Library\tms470.cml
	C:\Users\Public\Documents\DesignSpark PCB\Library\toshibatmp86.cml
	C:\Users\Public\Documents\DesignSpark PCB\Library\trans.cml
	C:\Users\Public\Documents\DesignSpark PCB\Library\transistor.cml
	C:\Users\Public\Documents\DesignSpark PCB\Library\vishay.cml
	C:\Users\Public\Documents\DesignSpark PCB\Library\xilinx.cml
	C:\Users\Public\Documents\DesignSpark PCB\Library\zilog.cml

Selected items to be updated:
-----------------------------

    Components:

	(None) 

    Symbols:

	(None) 

Additional items to be updated:
-------------------------------

    Components:

	(None) 

    Symbols:

	(None) 

Selected items not to be updated  (Same version as library)
-----------------------------------------------------------

    Components:

	28PIN2ROW1.27mmCON [C:\Users\Public\Documents\DesignSpark PCB\Library\eko_project.cml]

    Symbols:

	14x2CONN1.27mm  [C:\Users\Public\Documents\DesignSpark PCB\Library\eko_project.psl]

Update Components Summary
-------------------------

Updating single component.
Update component attribute values
(Remove pad style exceptions on updated components)

	Selected for update:			   1  Component 
						   1  Symbol 

	Selected items to be updated:		   0  Components
						   0  Symbols

	Additional symbols to be updated:		   0  Symbols

	Selected items NOT to be updated:	   1  Component 
	  (Same version as library)		   1  Symbol 

End Of Report.

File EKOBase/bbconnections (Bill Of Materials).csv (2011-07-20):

Component | Value | Description | Qty | Mfr | RS Order No. | RS Components | URL
+5V |  | Power | 2 |  |  | RS Components | http://uk.rs-online.com/web/ComponentFinder
+5V_ISO |  | Power | 2 |  |  | RS Components | http://uk.rs-online.com/web/ComponentFinder
0V |  | Power | 2 |  |  | RS Components | http://uk.rs-online.com/web/ComponentFinder
0V_ISO |  | Power | 2 |  |  | RS Components | http://uk.rs-online.com/web/ComponentFinder
28PIN2ROW2.54mmCON |  |  | 1 |  |  | RS Components | http://uk.rs-online.com/web/ComponentFinder
A4 |  |  | 1 |  |  | RS Components | http://uk.rs-online.com/web/ComponentFinder
F-1X02-SIP-100-40 |  | FEMALE HEADER | 1 |  |  | RS Components | http://uk.rs-online.com/web/ComponentFinder
F-2X02-DIL-100 |  | FEMALE HEADER | 1 |  |  | RS Components | http://uk.rs-online.com/web/ComponentFinder
F-2X04-DIL-100 |  | FEMALE HEADER | 1 |  |  | RS Components | http://uk.rs-online.com/web/ComponentFinder
FROM |  | Arrow L | 31 |  |  | RS Components | http://uk.rs-online.com/web/ComponentFinder
SM6T |  |  | 2 |  |  | RS Components | http://uk.rs-online.com/web/ComponentFinder

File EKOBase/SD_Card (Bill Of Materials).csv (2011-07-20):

Component | Value | Description | Qty | Mfr | RS Order No. | RS Components | URL
+1V8 |  | Power | 5 |  |  | RS Components | http://uk.rs-online.com/web/ComponentFinder
+3V3 |  | Power | 7 |  |  | RS Components | http://uk.rs-online.com/web/ComponentFinder
0V |  | Power | 9 |  |  | RS Components | http://uk.rs-online.com/web/ComponentFinder
2mmElectrolyticCap | 0.1uF |  | 1 |  |  | RS Components | http://uk.rs-online.com/web/ComponentFinder
06035C102KATDA | 0.1uF | Capacitor, Surface Mount Multi-Layer Ceramic | 5 |  |  | RS Components | http://uk.rs-online.com/web/ComponentFinder
A4 |  |  | 1 |  |  | RS Components | http://uk.rs-online.com/web/ComponentFinder
FROM |  | Arrow L | 10 |  |  | RS Components | http://uk.rs-online.com/web/ComponentFinder
R 0.1W SMTF 10K | 10K | Thick Film Surface Mount Resistor | 8 |  |  | RS Components | http://uk.rs-online.com/web/ComponentFinder
R 0.063W SMTF 33 | 33 | Thick Film Surface Mount Resistor | 12 |  |  | RS Components | http://uk.rs-online.com/web/ComponentFinder
SDBMF |  | SD MEMORY CARD PUSH-PUSH WITH CONNECTOR TYPE B (BIG SWUÌTCH #3)KINGFONT PRECISION INDUSTIAL CO., LTDSource: http://www.farnell.com/datasheets/74273.pdfBest.-Nr.: 9186174Hersteller: MULTICOMPHerstellerbez.: SDBMF-00915B0T2 | 1 |  |  | RS Components | http://uk.rs-online.com/web/ComponentFinder
SN74AVC4T774 |  |  | 2 |  |  | RS Components | http://uk.rs-online.com/web/ComponentFinder
TO |  | Arrow R | 2 |  |  | RS Components | http://uk.rs-online.com/web/ComponentFinder

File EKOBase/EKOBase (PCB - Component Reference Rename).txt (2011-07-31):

Old Reference         New Reference
-----------------------------------
D12                   D1                  
D11                   D2                  
D10                   D3                  
D9                    D4                  
D8                    D5                  
D13                   D6                  
D14                   D7                  
D4                    D8                  
D3                    D9                  
D2                    D10                 
D1                    D11                 
D6                    D12                 
D7                    D13                 
C28                   C1                  
C27                   C3                  
C25                   C7                  
C26                   C8                  
C34                   C9                  
C8                    C10                 
C23                   C12                 
C12                   C14                 
C9                    C15                 
C10                   C16                 
C15                   C18                 
C35                   C19                 
C19                   C20                 
C22                   C21                 
C21                   C22                 
C14                   C23                 
C18                   C24                 
C20                   C25                 
C16                   C26                 
C3                    C27                 
C24                   C28                 
C32                   C31                 
C33                   C32                 
C31                   C33                 
C1                    C34                 
U13                   U1                  
U14                   U2                  
U15                   U3                  
U18                   U4                  
U11                   U5                  
U12                   U6                  
U17                   U7                  
U2                    U8                  
U16                   U9                  
U6                    U10                 
U7                    U11                 
U8                    U12                 
U9                    U13                 
U5                    U14                 
U4                    U15                 
U3                    U16                 
U1                    U17                 
R52                   R1                  
R51                   R2                  
R50                   R3                  
R49                   R4                  
R48                   R13                 
R53                   R14                 
R54                   R15                 
R30                   R16                 
R55                   R17                 
R56                   R18                 
R60                   R19                 
R31                   R21                 
R57                   R22                 
R61                   R23                 
R28                   R24                 
R27                   R25                 
R29                   R26                 
R14                   R27                 
R59                   R28                 
R44                   R29                 
R4                    R30                 
R35                   R31                 
R33                   R32                 
R34                   R33                 
R15                   R34                 
R16                   R35                 
R43                   R36                 
R42                   R37                 
R32                   R38                 
R37                   R39                 
R38                   R40                 
R36                   R41                 
R17                   R42                 
R13                   R43                 
R1                    R44                 
R18                   R45                 
R3                    R46                 
R19                   R47                 
R2                    R48                 
R41                   R49                 
R40                   R50                 
R39                   R51                 
R58                   R52                 
R46                   R53                 
R47                   R54                 
IC5                   IC3                 
IC3                   IC4                 
IC4                   IC5                 
J5                    J1                  
J4                    J2                  
J1                    J3                  
J3                    J4

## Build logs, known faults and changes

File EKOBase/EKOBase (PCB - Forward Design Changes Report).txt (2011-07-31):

Forward Design Changes Report
-----------------------------

Report File    : C:\Users\ca508\Dropbox\eagle\eko-hardware-designs\EKOBase\EKOBase (PCB - Forward Design Changes Report).txt
Report Written : Monday, August 01, 2011
Project Path   : C:\Users\ca508\Dropbox\eagle\eko-hardware-designs\EKOBase\EKOBase.prj
Design Path    : C:\Users\ca508\Dropbox\eagle\eko-hardware-designs\EKOBase\EKOBase.pcb
Design Title   : 
Created        : 28/05/2011 14:42:59
Last Saved     : 31/07/2011 23:12:49
Editing Time   : 3044 min
Units          : mm (precision 4)

Ignoring PCB only pad X1.10 on net "0V"

The designs are the same, so no design changes to forward.

End Of Report.

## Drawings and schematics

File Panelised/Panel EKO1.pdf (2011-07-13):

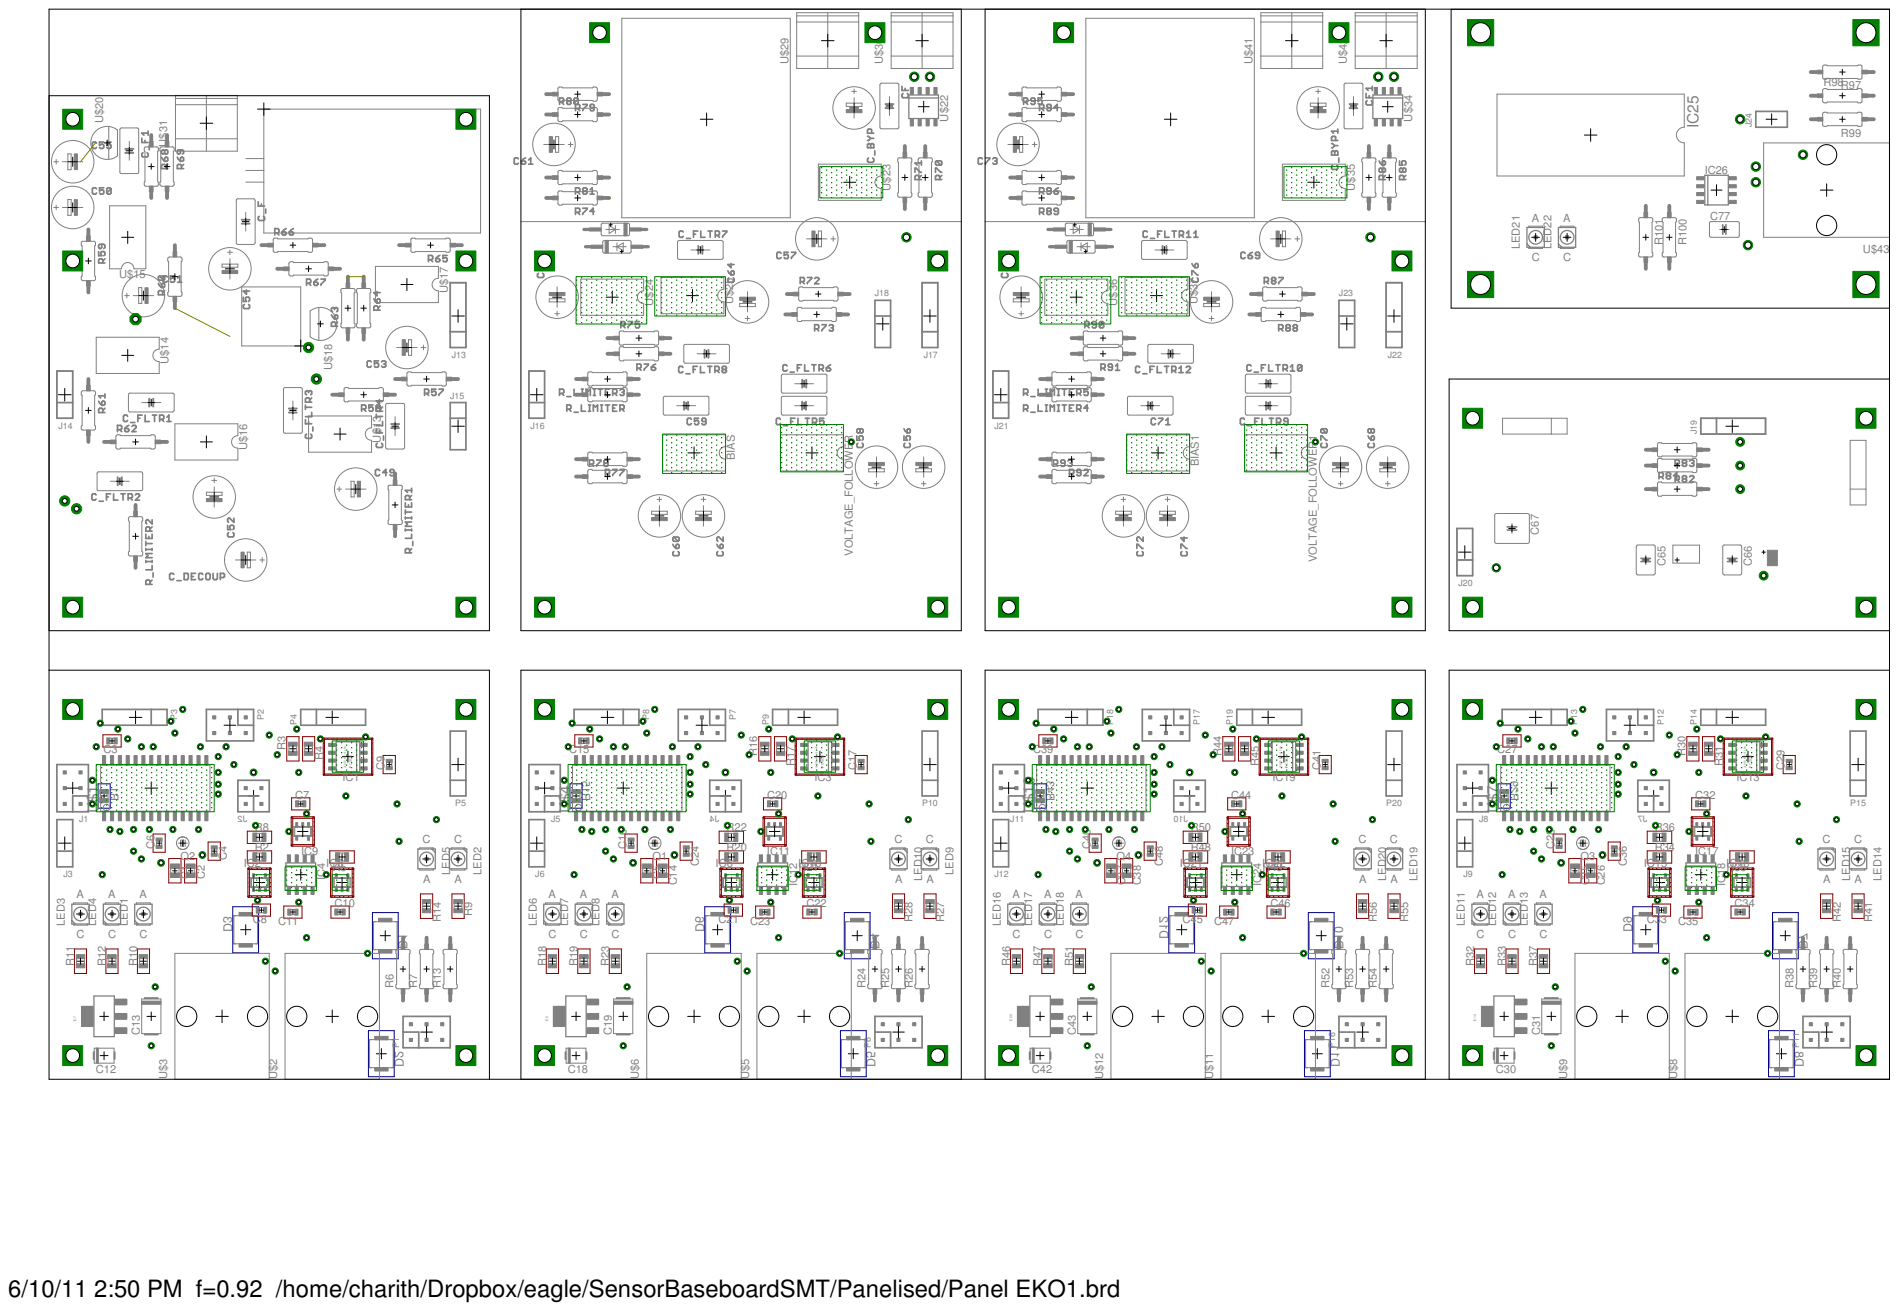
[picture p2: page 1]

6/10/11 2:50 PM f=0.92 /home/charith/Dropbox/eagle/SensorBaseboardSMT/Panelised/Panel EKO1.brd

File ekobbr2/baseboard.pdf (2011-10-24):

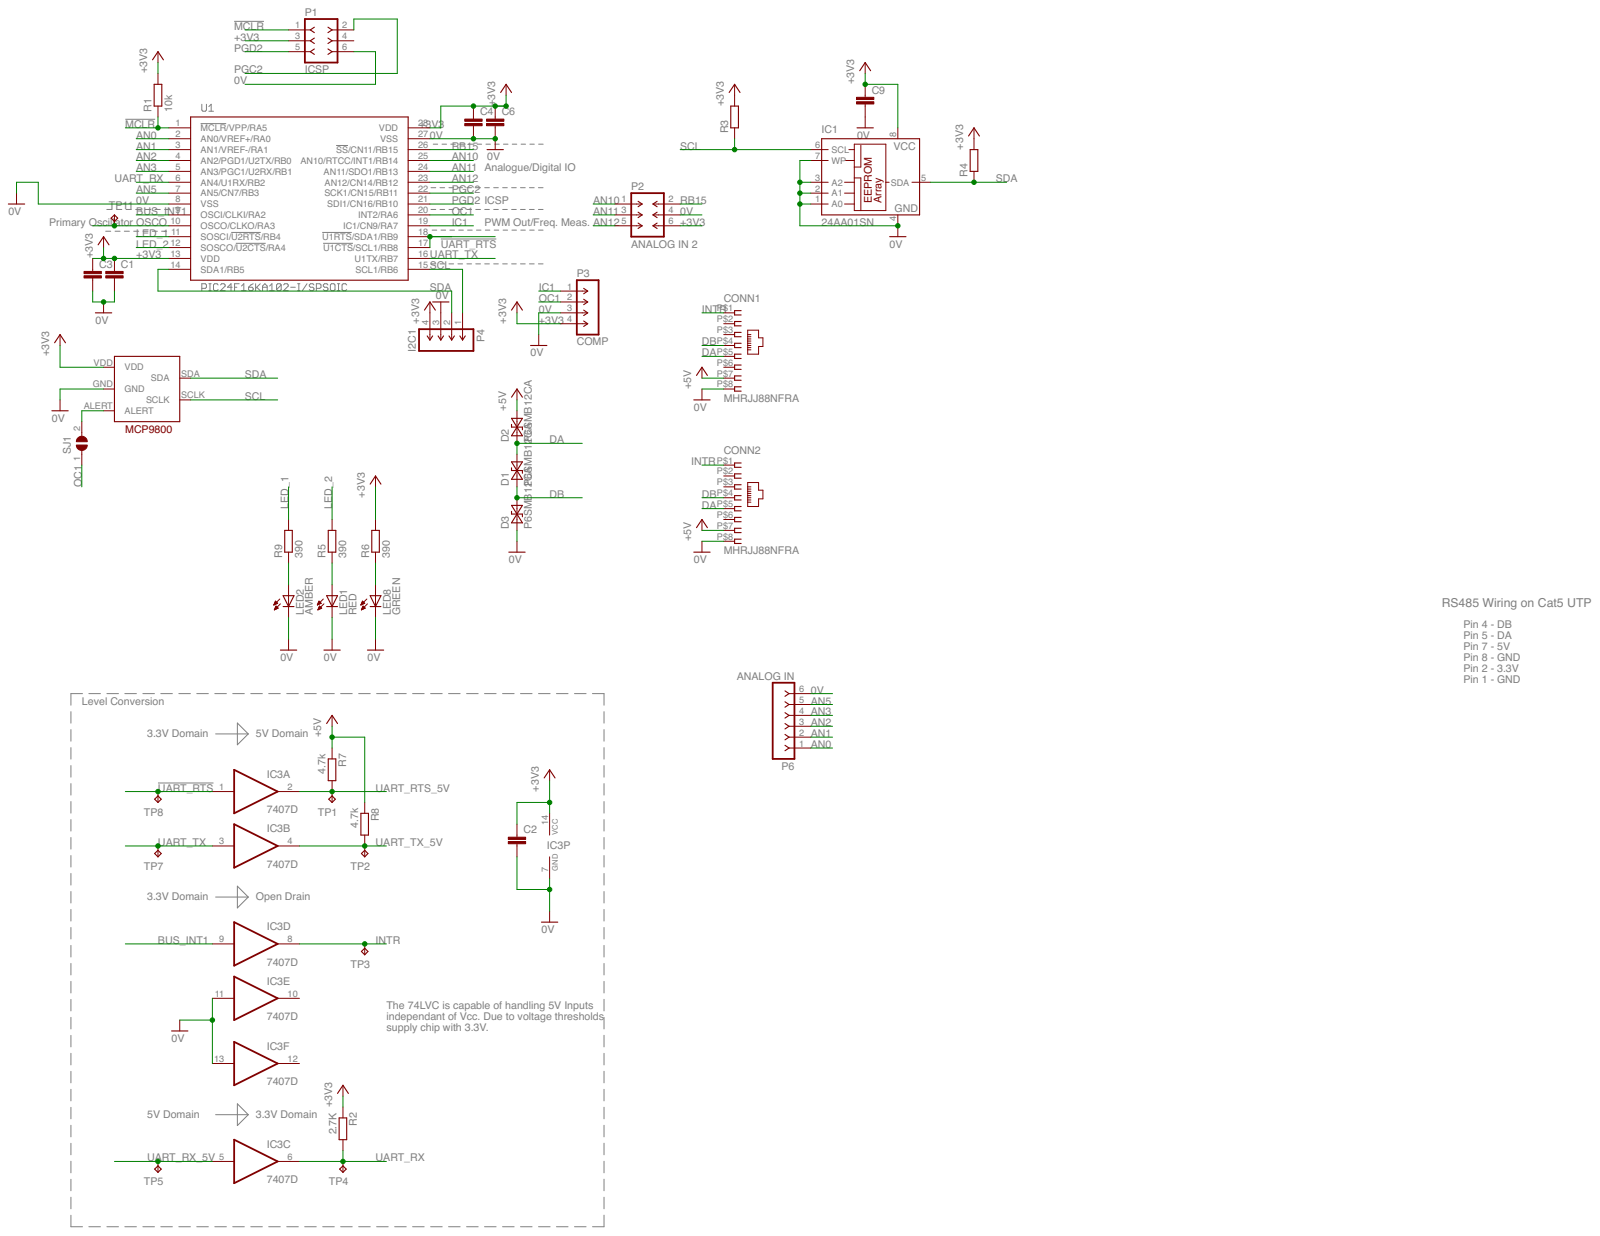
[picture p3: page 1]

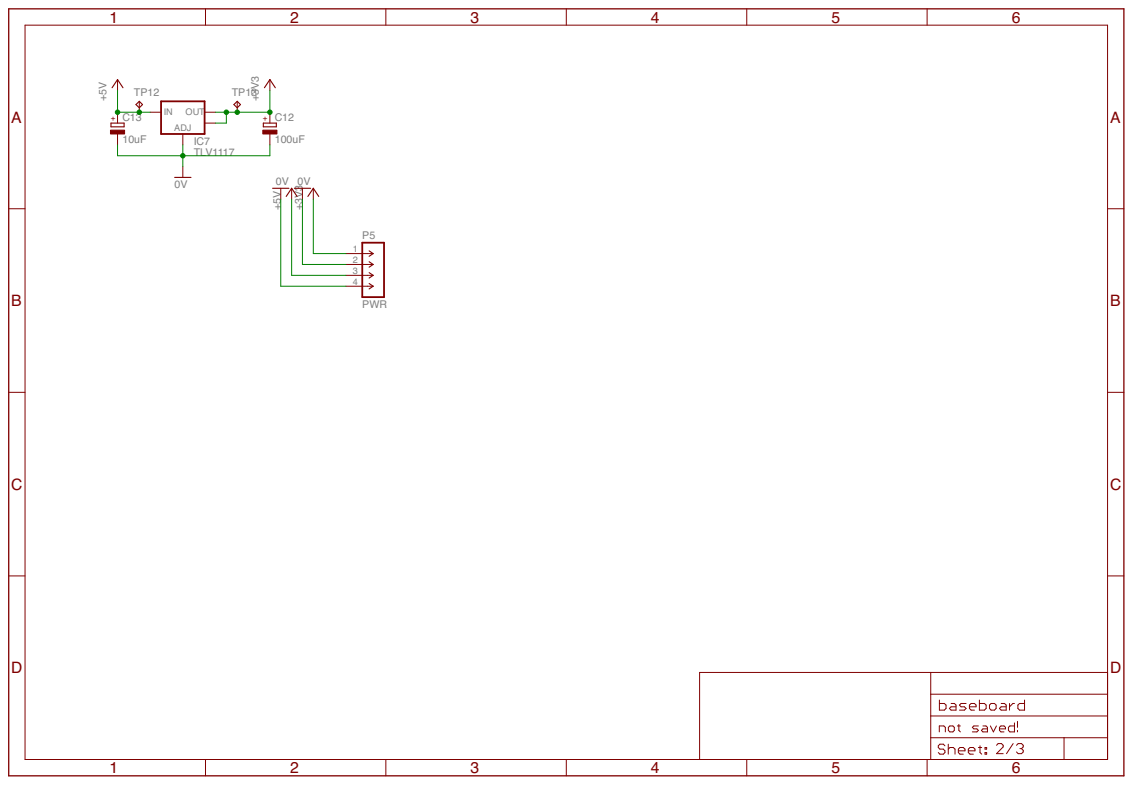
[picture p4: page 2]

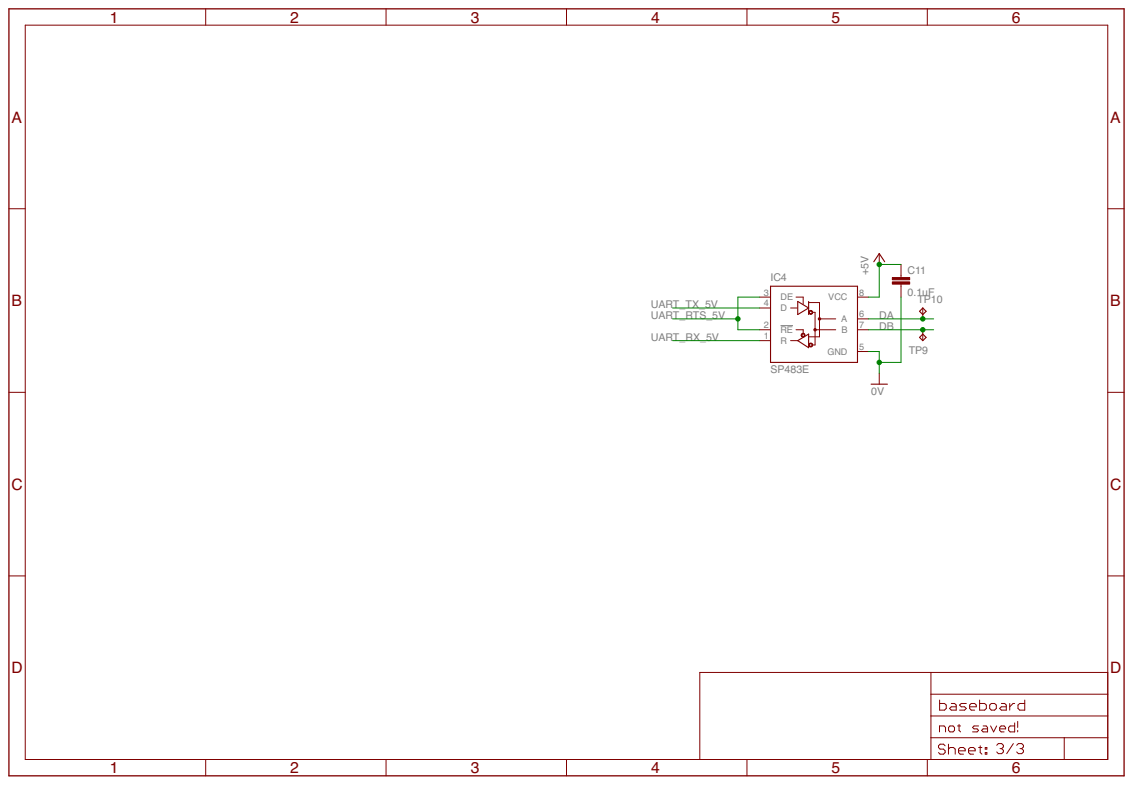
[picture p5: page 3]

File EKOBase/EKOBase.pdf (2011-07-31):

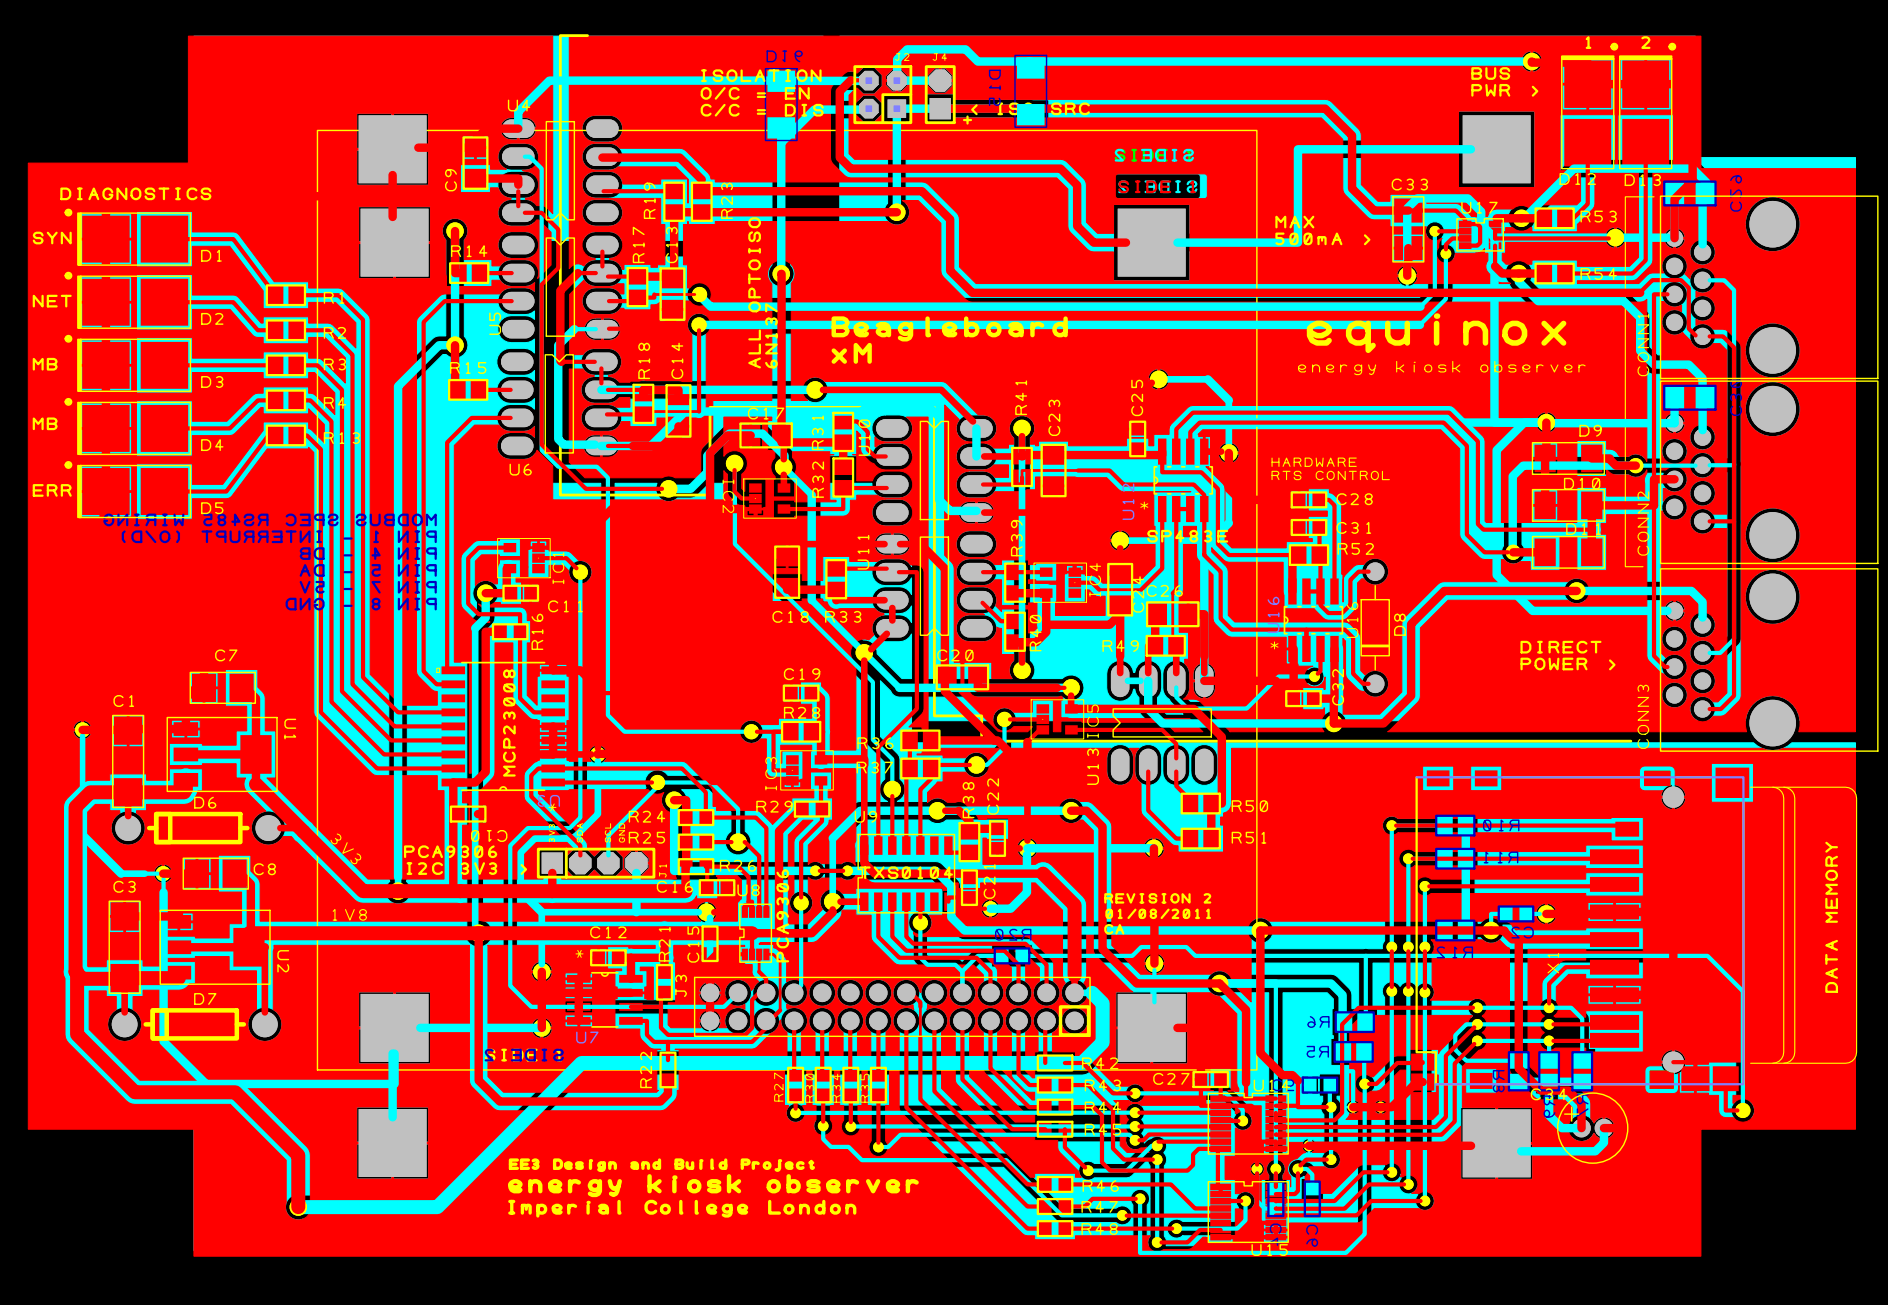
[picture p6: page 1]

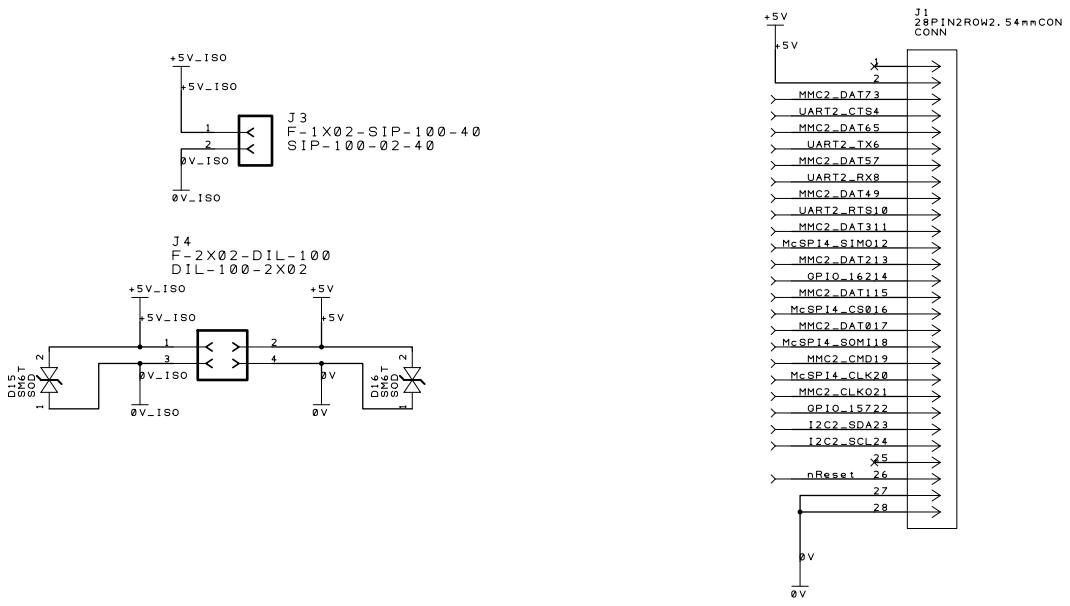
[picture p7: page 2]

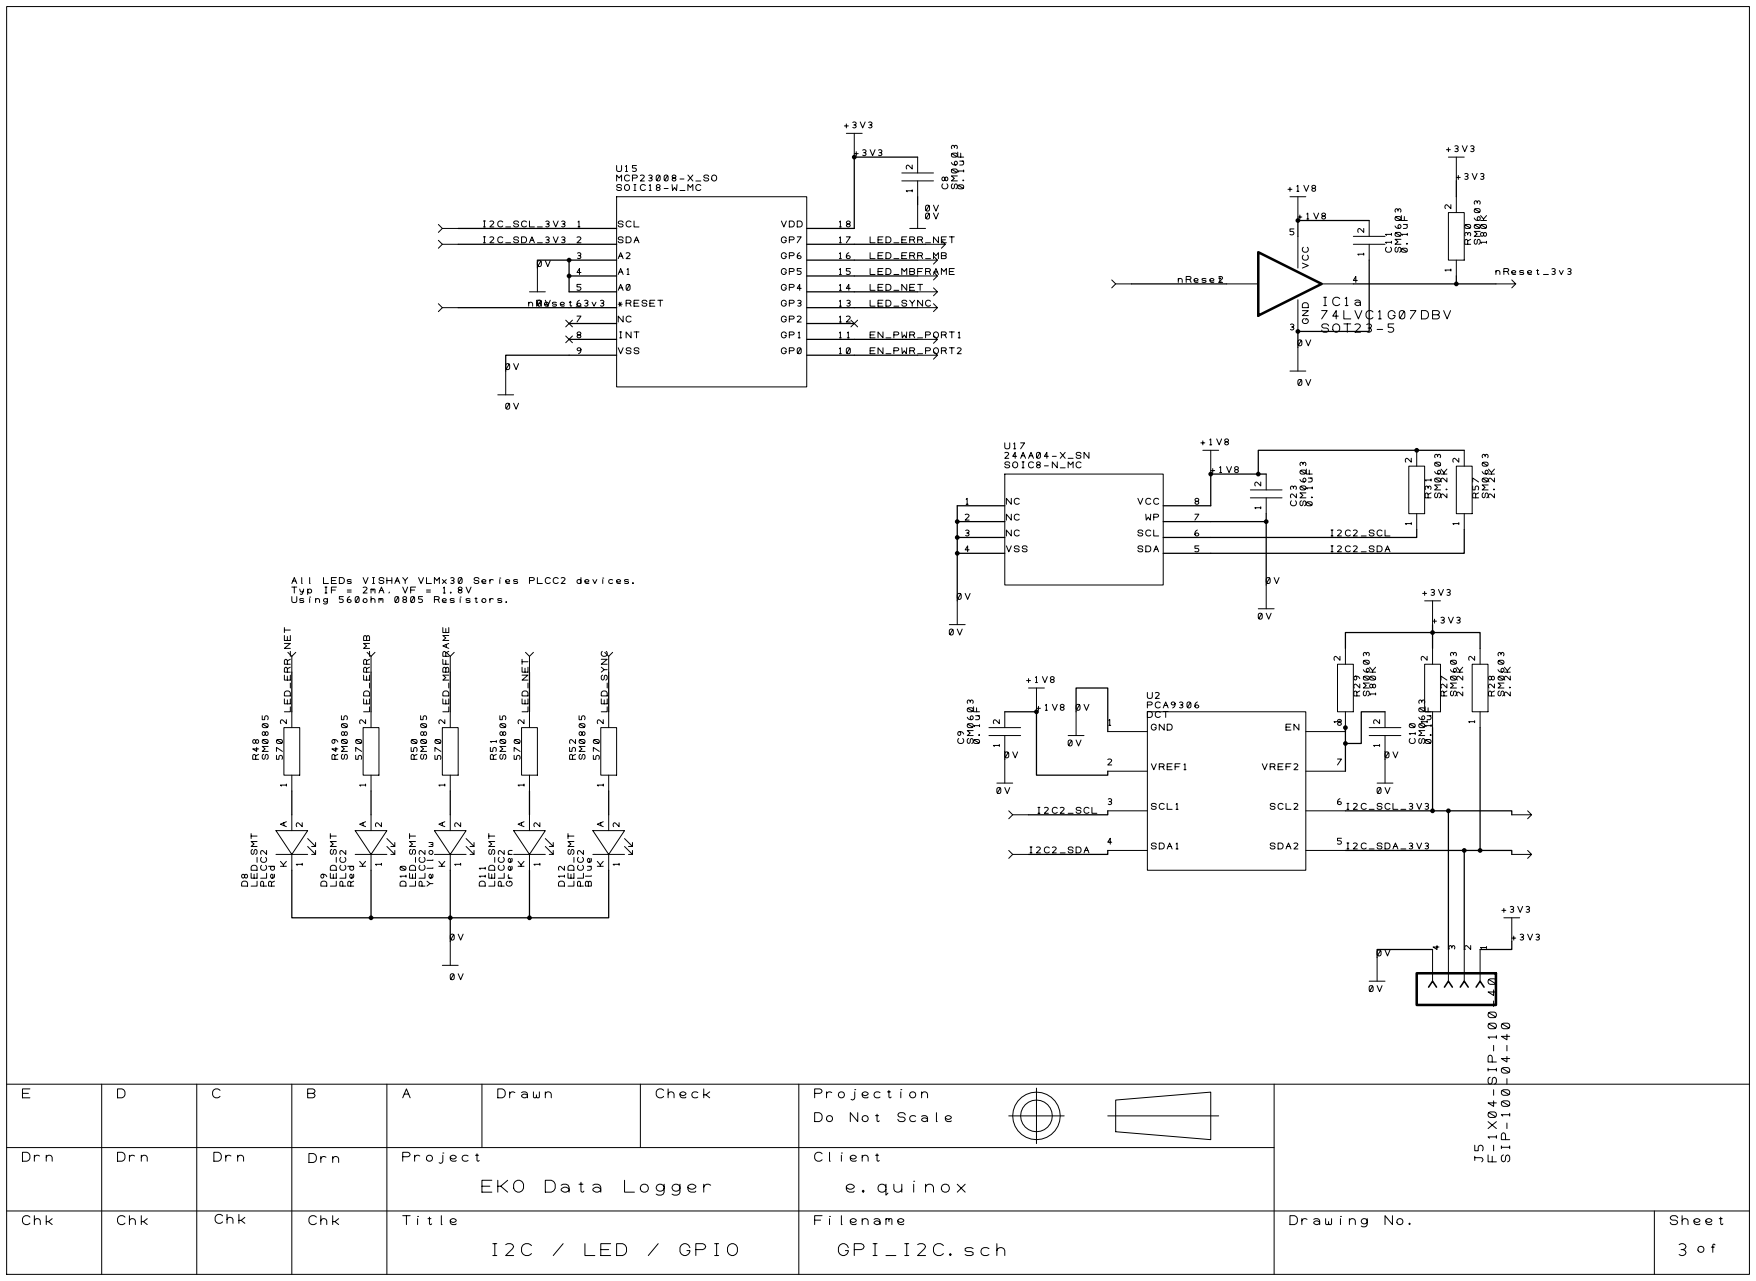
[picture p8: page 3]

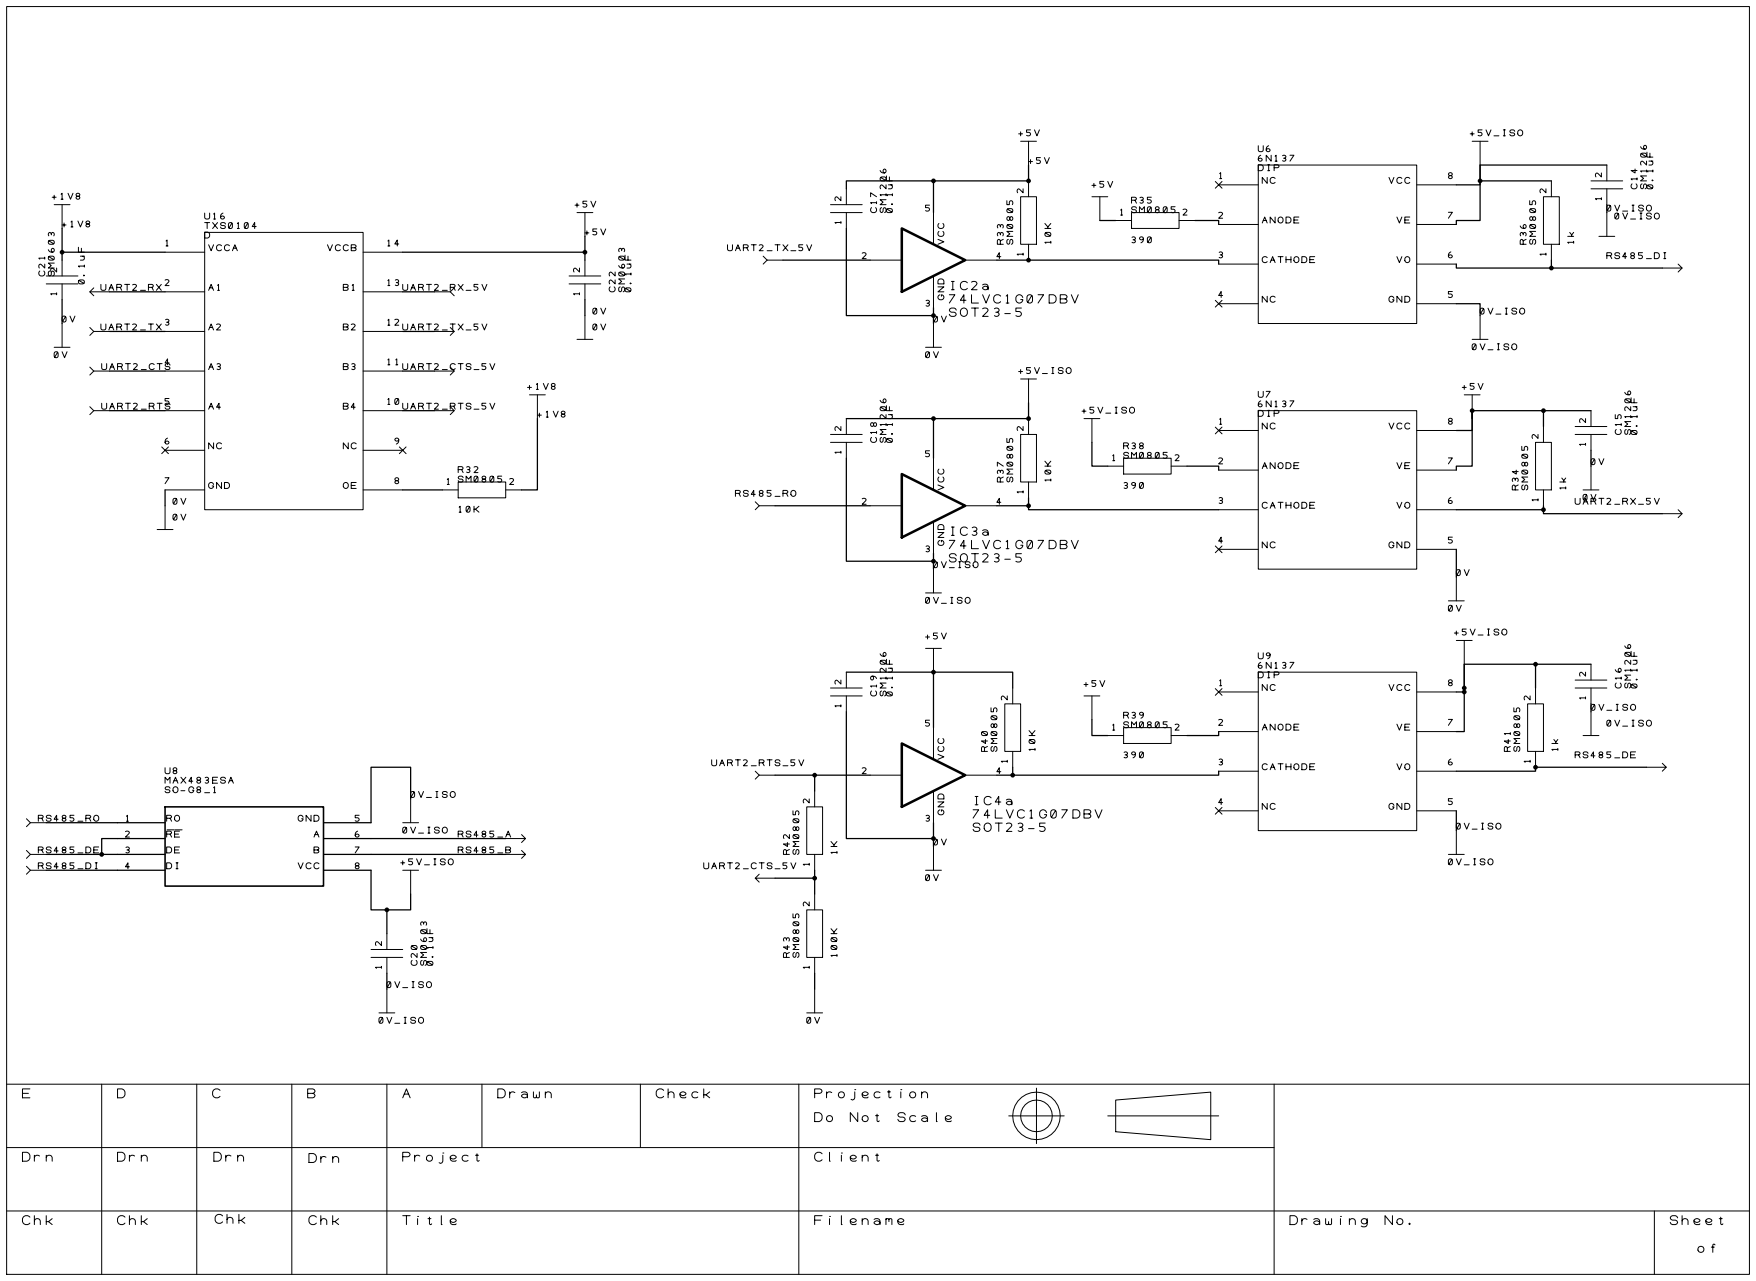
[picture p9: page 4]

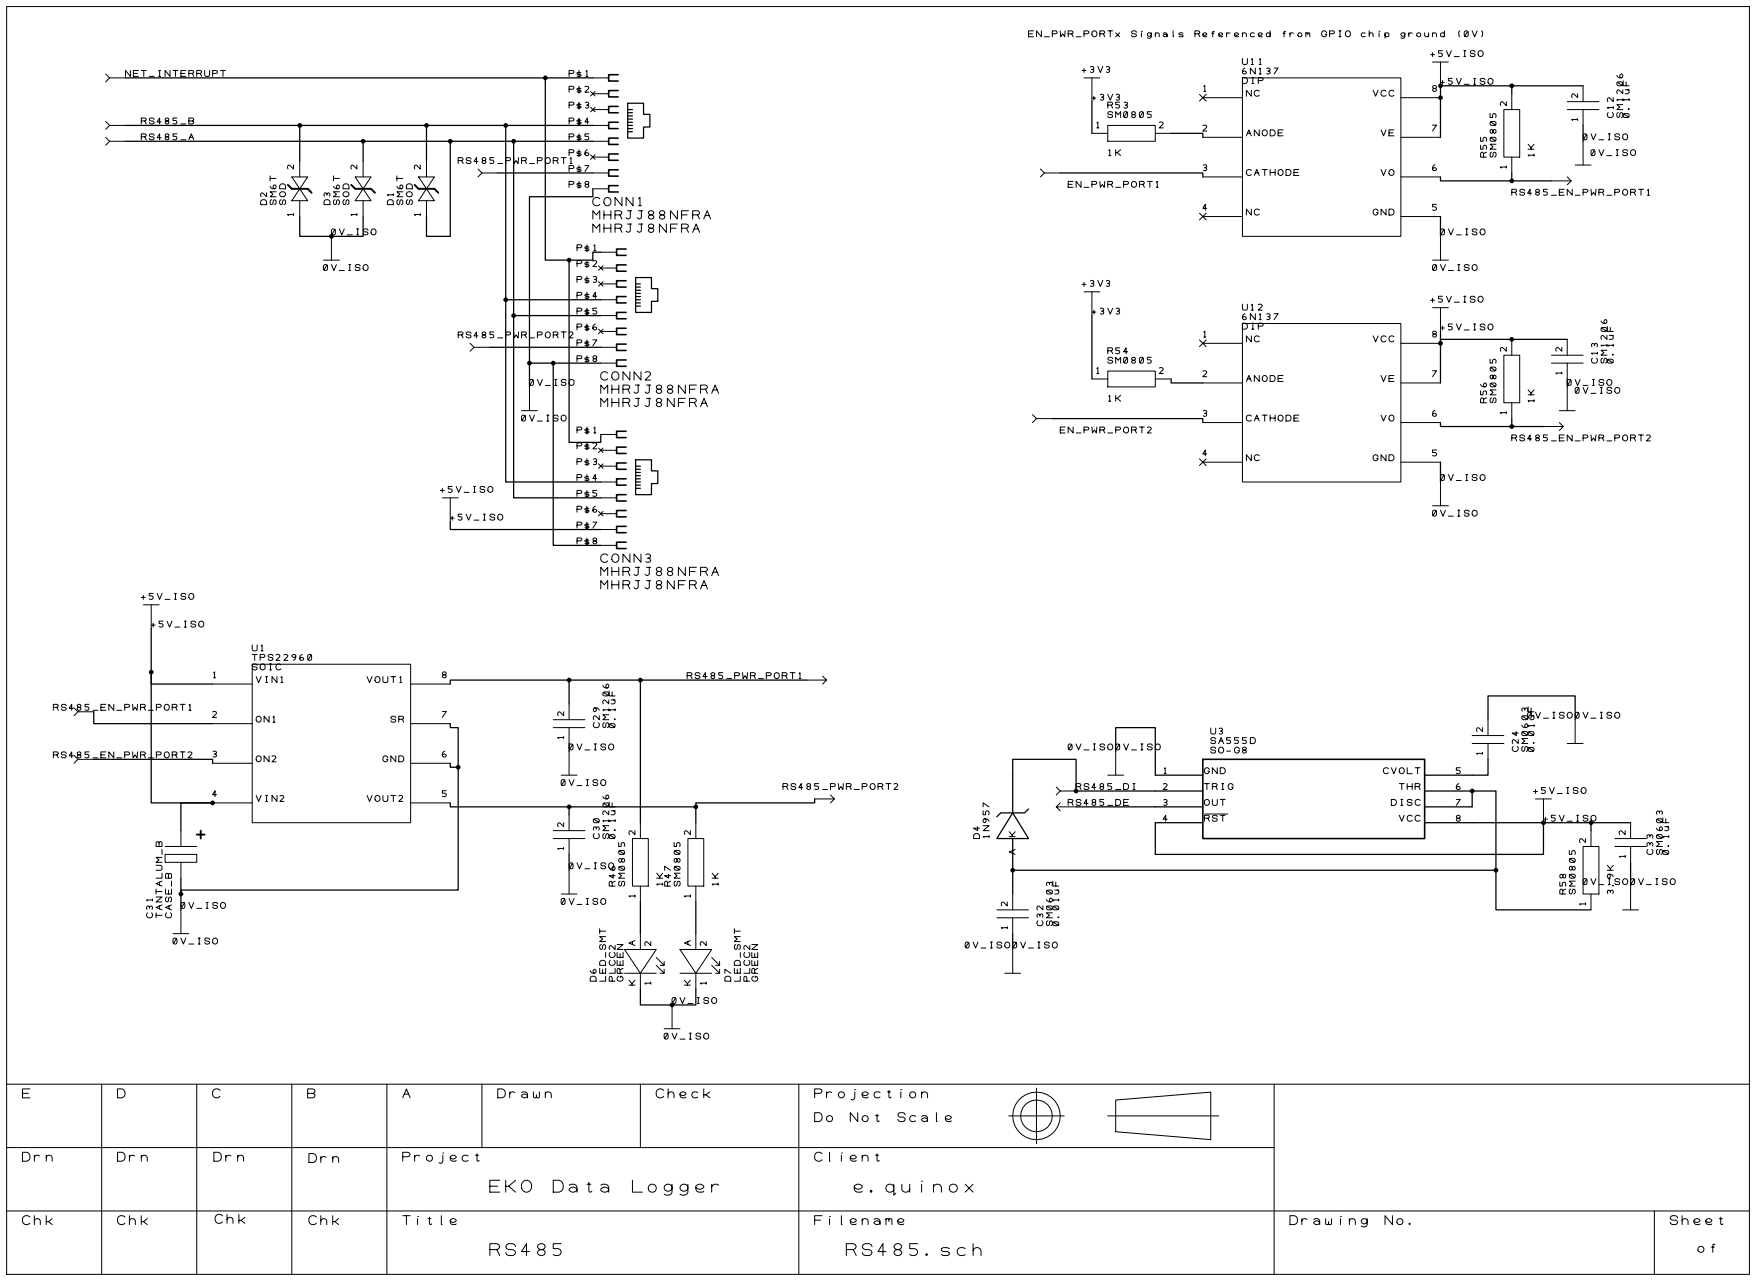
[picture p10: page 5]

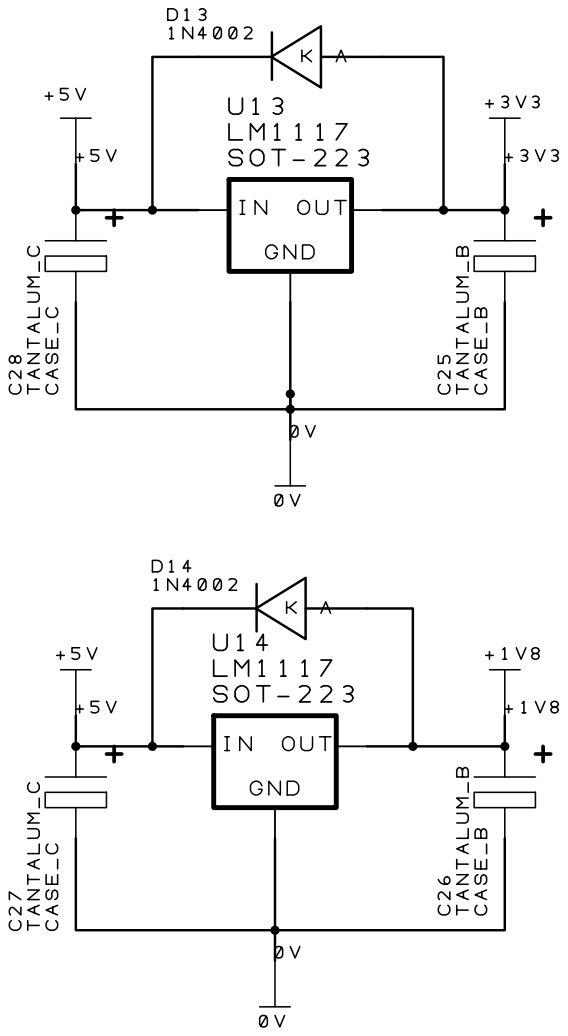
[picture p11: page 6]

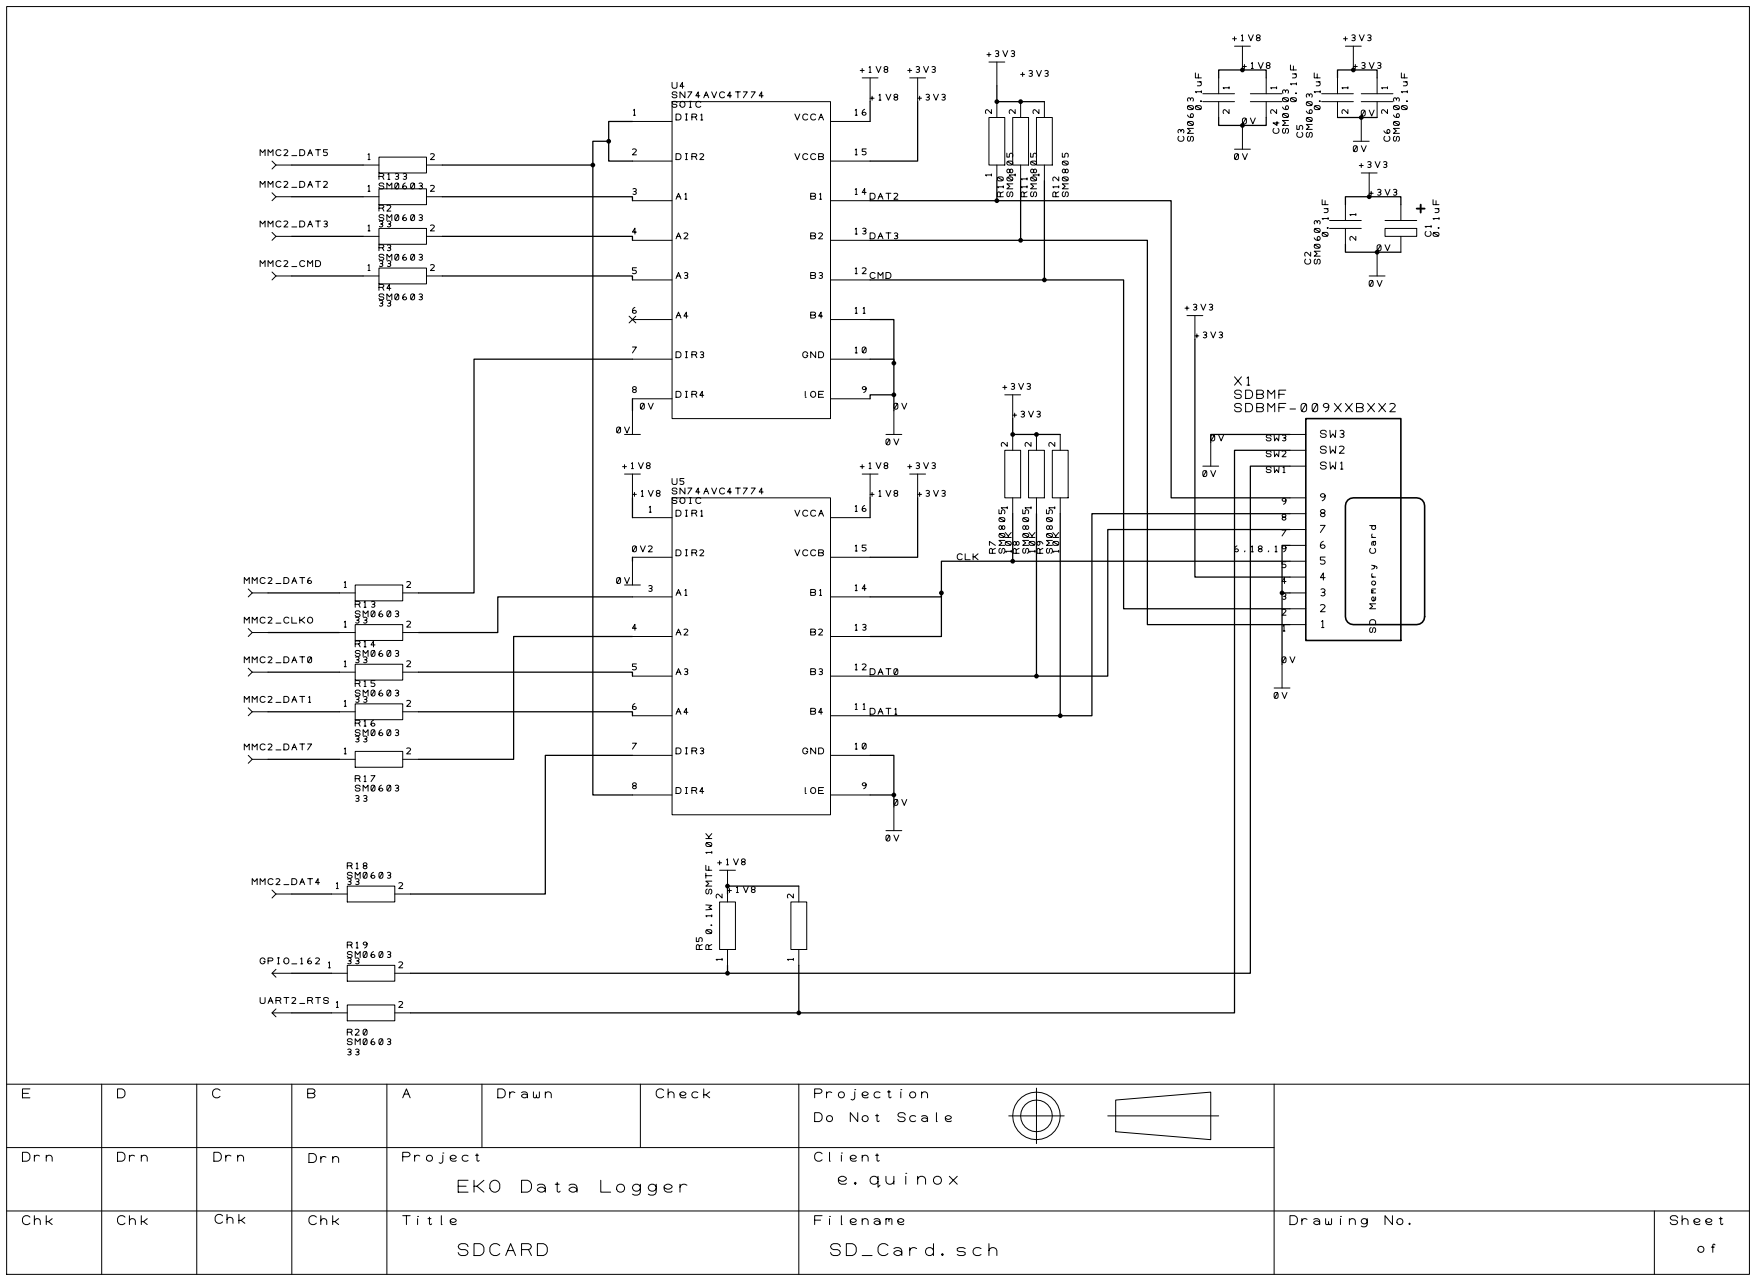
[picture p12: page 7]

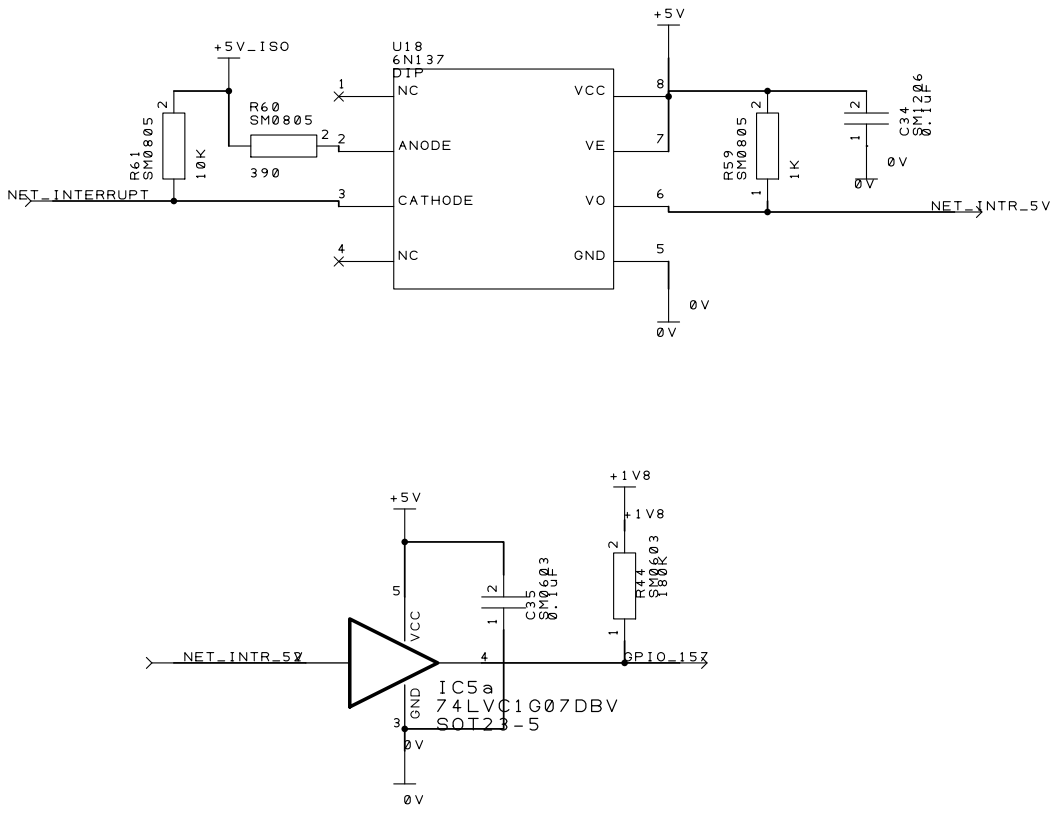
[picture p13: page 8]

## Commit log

2011-07-13 Initial commit of all up-to-date schematics and layout from the Energy Kiosk Observer Project
    2011 July : Department of Electrical and Electronic Engineering, Imperial College London
    Azrul Mohamad, Gonzalo de Gisbert, Charith Amarasinghe, Azubuike Ndukwe, Meng Siew, Masoom Miah
    [ACBoard.brd, ACBoard.sch, ACBoard2.brd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]
2011-07-19 Revision 3 PCB all connections made, added Interrupt line and connections to pins on the right side
    [baseboard.brd, baseboard.sch]
2011-07-20 committed EKO Beagle Daughterboard Rev1
    [EKOBase - Bottom Copper.gbl, EKOBase - Bottom Documentation.gbr, EKOBase - Bottom Silkscreen.gbr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]
2011-07-27 Updated rev 3 board to near complete status. Panelised/Panel EKO2.brd contains 6 baseboards.
    Fixes:
    * Decoupling caps added to ICs U1. IC1, IC3 and IC4
    * 3V3 and 5V Power Rails increased to 32mil width
    * Secondary oscillator removed. I2C temperature sensor added for on-the-fly FRC callibration.
    * Fixed DRC issues
    * Fixed node angles
    * Added M3 mounting holes and added extra clearance/symmetry
    Some additional bugs were also fixed:
    * Reversed UART_RX buffer direction and added pull-up to 3V3
    * Changed IC3 supply from 5V to 3V3 carrying forward from 74LVC datasheet threshold voltages
    * Removed LEDs on TX and RX lines, replaced with testpoints
    * Added MODBUS spec LEDs (Frame, Error and Power)
    *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
    [Panel EKO2.brd, baseboard.brd, baseboard.sch]
2011-07-27 Panelised layouts transferred to DesignSpark.
    The overall conversion has gone well except for a few issues with the clearances. These need to be manually verified with a gerber viewer.
    [Panel EKO2 - Bot Mask.gbr, Panel EKO2 - Bot Paste.gbr, Panel EKO2 - Bot Silk.gbr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]
2011-07-27 Converted Atmospheric Sensors to Designspark Panellised 3 Atmospheric Sensors with 4 Sensor base boards
    imported Traco Power library into Design Spark
    included DC/DC converter TEN_31211 in beagle baseboard but still needs to be connected properly
    [POWER.sch, ~POWER.sch]
2011-07-27 new copper routing in atmospheric sensors + panellised version of
2011-07-27 Fixed omissions from previous version: * GND and 0V nets were being used for Ground, GND and 0V were not connected. * Misc tweaks to silkscreen layer * Interrupt line was not connected to PIC. OSCI p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
    [Panel EKO1.brd, baseboard.brd, baseboard.sch]
2011-07-28 Imported into DesignSpark and created gerbers for 6 board panel of Rev3 baseboard
    [baseboard-r3-6panel - Bot Silk.gbr, baseboard-r3-6panel - Bottom.gbr, baseboard-r3-6panel - Dimension.gbr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]
2011-07-28 added bottom mask to plots since it was omitted accidentally.
    [baseboard-r3-6panel - Bot Mask.gbr, baseboard-r3-6panel - Top Silk.gbr, baseboard-r3-6panel - Top.gbr]
2011-07-28 added guide text for top and bottom mask layers.
    [baseboard-r3-6panel - Bot Mask.gbr, baseboard-r3-6panel - Top Mask.gbr, baseboard-r3-6panel - Top Paste.gbr]
2011-07-29 Updated EKOBase schematic and PCB ---------------------------------
    * Hardware Flow Control enabled through mono-stable operation of NE555 (U3)
    * Leave U9 and IC4 unpopulated for hardware RTS, U3 unpopulated for software RTS
    * Power switch replaced with TPS22960 which should work better. Added load capacitors.
    * Added top ground plane
    * Moved beagleboard to the left providing space for accessing the Ethernet and lower USB ports on the mounted beagleboard.
    Enhancements:
    * Increased board size to make best use of FIBOX enclosure
    * Added SD Card reader facility
    * Added third network port that is always powered
    * Added interrupt line connected to OMAP GPIO 157
    * Misc improvements to layo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
    [BusInterrupt.sch, GPIO_I2C.sch, POWER.sch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]
2011-07-31 Fixed DRC issues on mainboard. Renumbered components. Updated silkscreen text. Created production gerbers.
    [EKOBase - Board Outline.gbr, EKOBase - Bottom Copper (Paste).gbr, EKOBase - Bottom Copper.gbl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]
2011-08-21 New sensor designs and production ready baseboard. Consolidated eko-parts.lbr. Added RS485 barcode / display adaptor. Added solar panel sensor, 3 input. Added storage battery sensor and beagle power 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
    [ACBoard2.brd, ACBoard2.sch, Atmospheric.brd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]
